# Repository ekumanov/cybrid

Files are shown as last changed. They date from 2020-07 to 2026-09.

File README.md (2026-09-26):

# Cybrid

**Cybrid** is an open-source MIDI controller.

## Introduction

**Cybrid** is a DIY project I finished in 2020. The main goal was to turn a grand piano action into a MIDI controller.
In digital piano terminiology instruments with a real wooden piano action are called _hybrid_ pianos. I own
one such instrument, the Yamaha AvantGrand N1X which is a digital piano with real grand piano action and realistic
piano hammers that are stopped by a cushioning rail instead of strings.
There are optical sensors that detect the hammer velocity and produce digital piano sound.
In other words, it's a hybrid between an acoustic piano and a digital piano. I really like the Yamaha AvantGrand concept
and wondered if I can re-create something similar as a DIY project. Since I participate on various Internet piano forums
with the CyberGene nickname, another user suggested that I name the project Cybrid (from **Cyber**Gene and **hybrid**).

I am a Java engineer and had no prior experience with programmable boards, low-level programming, electronics, DIY,
woodowrking, metal working, piano regulation, etc. which is why it took me quite some time to learn the basics of all these
things and combine them to produce the final project. It is also why some decisions I made are rather clumsy
and the final result is not very polished. I'm glad this project served as an inspiration to other similar projects though.
Some of them are better designed and are also more easily reproducible.

Here's a demo of the finished Cybrid controller (ctrl-click on the picture to open the YouTube video in a new tab):

Watch the video (https://youtu.be/x7ZbjIRRwVg)

This GitHub project contains just the PCB design, the software and the mechanical
considerations/descriptions of the controller. It may be used "as is" for anyone willing to recreate that project, or
can evolve into a more advanced and improved design that can be used as a basis, or inspiration for other (hybrid or regular) MIDI-controllers,
etc.

If you would like to discuss this project, there's a discussion thread on
the [PianoClack Forum](https://pianoclack.com/forum/d/107-cybrid-a-diy-midi-controller-with-grand-piano-action)

## Brief description

### Main Principle

The goal of the project is to detect the velocity of the piano hammers and trasnalate it into MIDI velocity. This is realized by
using
[Vishay CNY70](https://datasheet.octopart.com/CNY70-Vishay-datasheet-5434663.pdf)
optical sensors and
[Texas Instruments LM339](https://www.ti.com/lit/ds/symlink/lm2901.pdf)
voltage comparators (LM339AD package).

**The main principle of using voltage comparators to turn continuous analog signals into digital binary signals has been
suggested by Marcos Daniel, a member of the PianoWorld forums. Everything else, including the multiplexing, PCB design,
Teensy code and integration with a real grand piano action has been done by me.**

* The CNY70 is an optical proximity sensor that consists of a photoemitter (a LED) and a phototransistor. The
  phototransistor will change its collector current depending on the proximity of subjects to the sensor
* By measuring the voltage drop created by the collector current on a resistor and comparing it to a reference voltage,
  we will know whether the subject is within a predefined proximity.
* A voltage comparator is a device that has two voltage inputs and a digital output. One of the inputs is a reference
  voltage selected through a trimpot and the other input is the phototransistor output voltage. If the phototransistor
  output voltage is higher than the reference voltage, the output of the comprator will be digital 1, otherwise it will
  be digital 0.
* Thus we can turn the continuous analog sensor signal into a discrete digital binary value that changes when
  the subject crosses a predefined distance

That is important because the LM339 voltage comparator is very fast when comparing two voltages. It takes just a few
nanoseconds to switch its digital state. That allows for a very fast distance detection, or more specifically whether
the hammer is either closer than, or farther than the preset distance point. In other words, the comparator will provide a digital output
of 1 whenever the hammer crosses that distance and stays closer to the sensor, and will switch back to zero when the
hammer crosses that point on its way back and moves away from it. By using that principle, we can avoid slow
analog-to-digital conversion. (As you will see in the following paragraphs, if we scan through all 88 keys of a piano,
and rely on just ADC to read the exact position of each hammer, might be a tricky task for many reasons.
First, because most programmable controllers such as Arduino/Teensy, etc. have only a few (1 or 2) ADC chips and a single
conversion takes microseconds which would cumulatively lead to inability to scan the entire keyboard without introducing
huge latency and without missing the very fast hammer motion. And second, even if fast ADC-s are used, it will require that we
multiplex analog signals and that's not a trivial task since there will be noise, etc.)

So, we can configure two preset distance points through two trimpots and use two voltage comprators. We will have two digital
outputs from the two comparators and by measuring the time it takes for the hammer to pass between the two points (i.e.
the comprators' outputs switch from 0 to 1), we can calculate velocity.

### Additional details

#### Multiplexing

A standard way of reading multiple sensors through limited number of inputs is through multiplexing, i.e. using
specialized chips that can
(roughly speaking) switch between multiple inputs and then channel them through a single line. However a particular problem
with this approach is that there is a switch delay and in this particular implementation scanning speed is of highest
importance. To work around that, we can use a programmable controller with as many inputs as possible, and one such board is the
[Teensy USB Development Board](https://www.pjrc.com/teensy/). It has 58 digital input/output lines.

#### Grouping

We can gather multiple scanned notes into a group, then select a group, read all the sensor data (each sensor outputting
two digital signals corresonding to two distances, as seen above), then switch to the nextg group, etc. until we read
all notes. In the current implementation, for a 88-key piano, we have 3 binary signals per note (see below why 3 and not
just 2) and a group is made of 5 notes. This means we have 18 groups
(the last group only contains 3 notes and not 5):

**18 groups x 5 notes** = 90 notes (-2 unusued in the last group) = 88 notes

**3 signals per note** = 15 signals per group

**18 groups x 15 signals** = 270 binary signal lines

Now, if we can enable only one group at a time, we can then read the 15 signals from each group by reusing one and same
15 input signal lines. Thus we will have 18 *group enable* lines from the Teensy (outputs) and 15 input lines shared by
all the 18 groups.

**18 outputs + 15 inputs = 33 digital input/outputs.**

Seems like we can go without using a mux/demux chips. Instead we will share inputs between groups. However, the problem
is if we just wire the corresponding inputs of the groups, and since they will continuously generate differing signals (
one group can generate high signal at the same time another group will generate low signal), it means they will be
short-circuiting themselves. To avoid that, we will use digital transceiver chips. A transceiver is a simple device that
has a certain number of digital inputs and digital outputs. It will repeat on the outputs the same digital signal that
it has on the corresponding input. Each transceiver chip also has an enable/disable line. When in disabled state, the
outputs will be in high impedance state (regardless of input signals), 
and that is how we solve the problem of short-circuiting. For the current solution we use
[SN74LVC245A](https://www.ti.com/lit/ds/symlink/sn74lvc245a.pdf) Octal Bus Transceivers With 3-State Outputs (
SN74LVC245ADWR package).

#### Circuit boards, wiring, power

There are three types of printed circuit boards

* **Sensor PCB** - these are very small PCB-s each containing a single CNY70 sensor and placed above each hammer shank base.
  In a 88-key piano there will be 88 of these. 5 of these connect to a single Note PCB.
* **Note PCB** - these are the group modules. Each one serves 5 Sensor PCB-s. Each Sensor PCB is connected through three
  wires (5V, signal, GND). There are three trimpots per sensor PCB, for setting the predetermined detection distances.
  The uppermost trimpot is for sensor 1 which is the closest distance to the hammer stop rail. The Note PCB-s also
  contain a jumper that is set to one of 18 positions to determine the group number of the Note PCB. Note PCB-s also
  have an IDC34 socket. The Note PCB-s should be aligned on a horizontal line and be connected through a single IDC34
  cable that has 18 IDC connectors. Each Note PCB has two power sockets. Each power socket has three lines (5V, 3.3V,
  GND). The two power sockets are wired to each other so that one can be used as power input and the other as power
  output for chaining to the next Note PCB. There are two voltages because the CNY70 sensors and the comparators are
  powered by 5V, however the digital signals from the transceivers as well as their power supply is 3.3V. The Teensy 3.6
  controller supports only 3.3V voltage (unlike Teensy 3.5 and older but they are slower)
* **Teensy PCB** - this one contains the Teensy controller, an IDC34 socket for controlling the Note PCB-s, power
  inputs/outputs to chain to the Note PCB-s, and possibility to connect other devices (e.g. a sustain half-pedal to the
  analog inputs.) It has s USB-B input that's used only for power input. The Teensy controller itself has a micro-USB
  for connection to the computer to transmit MIDI. The Teensy controller itself is powered through that USB connection.
  Everything else requires an external power, for instance using the USB-B input socket. In the current implementation
  an iPad charger is used and it's sufficient to provide 2W of power which is the entire consumption. On the Teensy PCB
  there's also a jumper that can draw 3.3V power from the Teensy controller and send it to the Note PCB-s, however
  that's not recommended since there might be short circuits or problems with the Note PCB-s that can burn the Teensy.
  In the current implementation a pretty simple 3.3V voltage regulator is added through a small customized breadboard
  attached to the Teensy PCB, drawing from the 5V power.

The PCB-s are designed in the free KiCad editor.

**To Be Done** (a BOM or list with exact elements)

#### Scanning algorithm

The program is written in the Arduino compatible language of Teensyduino. It would sequentially enable each Note
module (a note module is serving 5 notes x 3 inputs). For each module all the 15 inputs are read. For each optical
sensor there are three predefined sensor distances (set through trimpots and with the calibration utility programs) that
are referred to in the code as sensor1, sensor2, sensor3. Sensor3 corresponds to the damper being removed from the
string, it is halfway from the hammer travel. Sensor 2 is where escapement happens. Sensor1 is where the hammer touches
the rail (in reality it should be a bit further to allow for the scanning logic to catch that moment because the hammer
will rebound quickly and sensor1 will be activated for only a brief moment).

***Active low* logic is used.**

Sensor distance signal lines stay active as long as the hammer is at this distance or closer to the rail. This means
when sensor1 is active (low), sensor2 and sensor3 are also active, etc.

When the hammer activates sensor2 for the first time, it means we
"start" measuring duration and we remember the timestamp of that event.

When the hammer activates sensor1 for the first time, it means we have a
"hit" and so we produce a MIDI note-on event based on the duration. A velocity is obtained through an in-memory map that
holds logarithmic velocity values that have been pre-calculated.

On its way back, if the key is held, the hammer will stay within sensor3 activation region and so the sound will
sustain. Once the key is released, the hammmer will deactivate sensor3 (high signal) and that's when MIDI note-off is
sent.

**These timestamp recordings and events are recorded sequentially
(group by group, input line by input line), because we want to give equal chance for each event to be recorded as soon
as it happens. For instance, once we read the event "hammer passed through C4 middle sensor" we will continue scanning
other keys and sensors and we will be able to check that hammer then passed through C4 sensor 1 (i.e. a hit)
only on the next full loop. Therefore it's of the highest importance that there's no delay in any scanning speed. The
fastest the entire loop finishes, the more precise the velocity calculation will be.**

#### Building the firmware

The sketches are in `src/teensy` (main firmware in `main/`, calibration utilities in `utils/`), each in its own
folder so they open directly in the Arduino IDE with [Teensyduino](https://www.pjrc.com/teensy/td_download.html)
(set *Tools > USB Type* to *MIDI* for the main firmware).

They can also be built with [PlatformIO](https://platformio.org/) using `platformio.ini` in the repository root:

* `pio run` builds all sketches (V1.3, V1.2 and the three calibration utilities) for Teensy 4.1
* `pio run -e v1_3 -t upload` builds and flashes the main firmware (`v1_3_teensy36` targets a Teensy 3.6)

`test/host/run.sh` runs the firmware against a simulation of the V1 hardware on the computer. It checks that the
firmware never makes two outputs fight on the cable or bus, and that it behaves like a grand piano action (one note per
stroke, faster hammer = louder, repetition with the key held, aborted presses, rail rebounds). It also compares the
MIDI output with a reviewed reference (`test/host/expected/v1_3.txt`), so any change in behaviour shows up as a diff;
accept an intended change with `UPDATE_EXPECTED=1 test/host/run.sh`. GitHub Actions runs these tests and builds all
sketches on every push; the `.hex` files can be downloaded from each run's artifacts and flashed with the Teensy Loader.

TBD (velocity map calculation) for quick calculation a velocity map is pre-calculated on program startup and held in
memory to allow for a quick "
duration -> MIDI velocity" value to be read from memory rather than being calculated all the time (since it also
includes logarithms, etc. which is slow.)

TBD (group velocity offset calculation) the high keys hammers are lighter than the low ones. If we don't account for
that, the produced MIDI velocity value is too high and the key sounds too loud. Therefore an offset needs to be applied
and pre-calculated, so the velocity map is actually further split into groups (
corresponding to the note PCB groups.)

TBD (half-pedal mapping) uses the ADC module.

#### Calibration

_(Copy-paste from a forum discussion)_

If you mean the Calibrate_Sensor_1/2/3 programs in the utils folder, those are actually temporary programs meant to assist in calibrating the sensors. Let me do some explanations first:

Not sure why I used the confusing word "sensor" but I actually meant sensor "point". Each optical sensor is used to detect three predefined distances of each hammer:

- Point 3: Hammer at half the distance between rest point and stop rail. When the hammer is above that point, I consider this as the damper being lifted, so once I detect a hit and send a Note ON event, then I will wait for the hammer to drop below this point and is when I will send Note OFF.
- Point 2: Hammer at 1mm from the stop rail (this is where hammer is released from the jack, i.e. the escapement), we start measuring duration from this point
- Point 1: Hammer at (or very close to) the stop-rail, this is where we stop measuring duration and derive velocity from it

Now, through the trimpots you set where those three distances for each sensor (hence hammer) are. In order to quickly do that, I created the three helper programs for each sensor point.

Here's the procedure:
- Upload the corresponding program for the corresponding "sensor" point (1, 2, 3).
- The program is a very simple logic that detects if any sensor (for any hammer) is at a distance equal or closer to the corresponding point and if true, will lit the Teensy LED

To facilitate the initial rough calibration I use:

- A simple wooden block that has such dimensions that when I put it at the stop-rail and lift the hammer, so that the hammer touches the block, then hammer is at exactly half the blow-distance (point 3).

- I use a thin plastic strip with 1mm thickness for point 2.

- For point 1 I just lift the hammer until it touches the stop-rail.

- So, depending on which of these three utility programs are loaded, I use the corresponding wooden block, or strip, or the stop rail itself, and I lift each hammer one by one until it touches the wooden block, the strip or the stop-rail. And I observe the LED and turn the corresponding trimpot until the LED is lit.

Once I am ready, I then upload the main program loop and surprisingly the above calibration is already pretty close to the final result and the piano is pretty playable at this point. It takes less than 10 minutes to do the above and I doubt you have to do it often once performed for the very first time.

I then perform a finer manual adjustment without any tools, only playing the keys one by one and I devised the following procedure:
- I play staccato notes with a high velocity and adjust the first position so that the corresponding key stops being detected. That means that I set the point way too high and the hammer cannot reach it because it's stopped by the rail before it. Then I begin to slowly back off until the hammer "appears" again. If you stop at that point, you will notice that very low velocity might still be missed because the stop-rail cushioning is not compressed enough to trigger it. Or, very high velocity strikes get missed because they are so quick, and the point is set so high, that the scanning doesn't have enough time to detect the hammer while at the point 1. That's why we need to give it some leeway and back off enough the trimpot, so that the hammer is always detected in the peak point, regardless of velocity. Once there, we have the top point set at a good enough distance
- We then proceed to fine-setting the second point. Because adjusting the first point effectively changes the distance between it and the second point, it effectively changes the loudness of that hammer. So, I proceed fine-tuning the second point by ear, choosing a realistic velocity response of the key. This might sound like a very demanding task but surprisingly for me, it is a satisfying thing to do, since I felt like a real piano master who fine-tunes his piano. And actually it's very easy to feel where the good position is.
- I will optionally fine-tune the third point to be where I need the note OFF to happen. My experience is it's not very important.

People often comment on how the above procedure is the main reason they didn't like that solution and how tedious it is, but in fact it's a pretty quick procedure that takes no more than 20-30 minutes in total and is required only the very first time. From there on, only an occasional touch-up is needed. 

### Mechanical Piano Considerations

TBD

### Known Problems

TBD

* stable power with low-ripple is very important. Currently the power comes from a USB-B socket and is chained through
  wires from the Teensy PCB to all the Note PCB-s. This is not a good solution and needs improvement.

### TBD (more details coming...)

### Misc Info

**Because I've been communicating with some people and got some questions, I will paste here raw excerpts from emails if
it can help.**

All SMD elements are of 0603 size/footprint which according to my research at the time was the smallest possible size
that's still possible to be hand soldered. It's pretty tiny as it turned out, so I used one of those specialty glasses (
for jewelry, etc.) that you put on your head with changeable magnification glasses.

There are three resistor values that have been used:

240 Ohm one on each sensor boards: https://store.comet.bg/en/Catalogue/Product/9812/

4.7 kOhm (5 on each module board R18, R28, R38, R48, R58, these are the resistors that are on top of the module board
above the trimpots): https://store.comet.bg/en/Catalogue/Product/9910/

10 kOhm - all other resistors: https://store.comet.bg/en/Catalogue/Product/35586/

On the Teensy board I haven't soldered any resistors. My idea was to limit current draw for powering sustain pedals, so
there's place for resistors but that needs to be calculated ad hoc. I was in a hurry, so haven't limited the Kawai pedal
but there seems to be no problems.

All capacitors are 100 nF (there are 6 capacitors on each module board **on the back side**, they are the only elements
to be soldered on the back side besides the sockets that connect the sensor
boards): https://store.comet.bg/en/Catalogue/Product/50624/

The trimpots are 10k, however due to insufficient quantity I also purchased 20k, I think it makes no difference:
https://store.comet.bg/Catalogue/Product/5925/
https://store.comet.bg/en/Catalogue/Product/6318/

The comparators are LM339AD and are through the Farnell
catalog: https://store.comet.bg/en/CatalogueFarnell/Product/1895017/

The transceivers are SN74LVC245ADWR, however they seem to not be available anymore. I see a similar
part (https://store.comet.bg/CatalogueFarnell/Product/506771/) which is however TSSOP-20 and I'm not sure if its
footprint is the same as SOIC-20 as the original part. Needs to be checked. (P.S. Seems like half the size, so not
compatible)

P.P.S. The transceivers are available at
Mouser: https://eu.mouser.com/productdetail/texas-instruments/sn74lvc245adwr?qs=WzgTT80quPGdOFCXqni3uA==

Here are some of the other parts I ordered:
https://store.comet.bg/en/Catalogue/Product/5003090/
https://store.comet.bg/en/CatalogueFarnell/Product/291323/
https://store.comet.bg/en/Catalogue/Product/286934/
https://store.comet.bg/en/Catalogue/Product/10079/#e30%3D
https://store.comet.bg/en/Catalogue/Product/10151/
https://store.comet.bg/en/Catalogue/Product/10151/
https://store.comet.bg/en/Catalogue/Product/2944/#e30%3D
https://store.comet.bg/en/Catalogue/Product/3116/#e30%3D
https://store.comet.bg/en/Catalogue/Product/17820/#e30%3D (soldered on the backside of the module board, facing the
sensor boards, so that short 10cm three-wire female-female dupont cables I ordered through some Chinese eBay seller can
be used to connect each sensor board to the module boards, I don't have the link for the cables anymore)
https://store.comet.bg/en/Catalogue/Product/20826/ (I cut those into smaller 3-pin pieces which was PITA, these are the
corresponding connectors on the sensor boards to the above part. Before attaching these two parts you need to really
check what the mechanical placement will be of your sensor boards and module boards on your piano and from there to
decide whether you need angled or straight sockets, etc. their orientation, whether you mount them on the backside of
the sensor board or probably an angled one on the front or back, etc. it's flexible and depends on your construction and
ability to connect in either straight line or probably a n arced cable... I thought a lot on that and ultimately decided
on my current variant visible also in the pictures)
https://store.comet.bg/en/Catalogue/Product/48762/ - used to daisy-chain power from a module board to module board, two
of these per module board

Regarding the CNY70 sensor, it's soldered so that the writings/label on the sensor-cube (there is some text only on one
of its sides) is next to the label "
CNY70" on the sensor board. The chips are soldered so that the notch (small marking/hole) matches a corresponding small
circle printed on the PCB.

To daisy-chain the power between module boards I used single-core hard cables that I bought from a hobby-shop, those
cables are used for breadboards.

On the Teensy board there's the possiblity to connect a jumper that will get the 3.3V from the Teensy but I wouldn't
recommend it and I don't use it. Intead I used an improvised 3.3V regulator that is getting 5V from the main USB-power
line (the iPad charger), look at the pictures, a bit awkward but works. I don't remember the regulator part, I bought by
asking on the store but there's some writing on it and I can shoot it. But I guess every regulator will work since the
3.3V consumption isn't high.

On each module board you need to use a jumper to denote the module board index by which it will be read by the software.
On the left side of the IDC connector top to bottom are 1-9, and on the right side top to bottom are 10-18, you start
with 1 at the lowest part of the keyboard.

Making the IDC cable is major PITA. I created my own clamping contraption, you can see it on the pictures. Make this
your last step because the sensor boards are not equally spaced because due to the action brackets the hammers are
grouped and so some module boards will not be centered behind adjacent 5 sensors but would be behind 5 sensors with a
bracket in between. So once you mount the module boards, then you design the IDC cable. And mine was made intentionally
wavy because I already wasted one trying to make it straight but that's a difficult task.

Also, seems like a I screwed up the Teensy IDC orientation and so to make the IDC cable finally connect at the Teensy
without twisting it, the Teensy board needs to be upside-down

For the sustain pedal, I power it from the Teensy PCB and it's connected to A21 on that board, however they swapped it
between Teensy 3.6 and 4.1, so on the 4.1 that's not A21 but luckily it's still an analog input with another name, can't
remember, maybe A20 (see in the code I have a comment for whether you use 3.6 or 4.1).

### Pictures

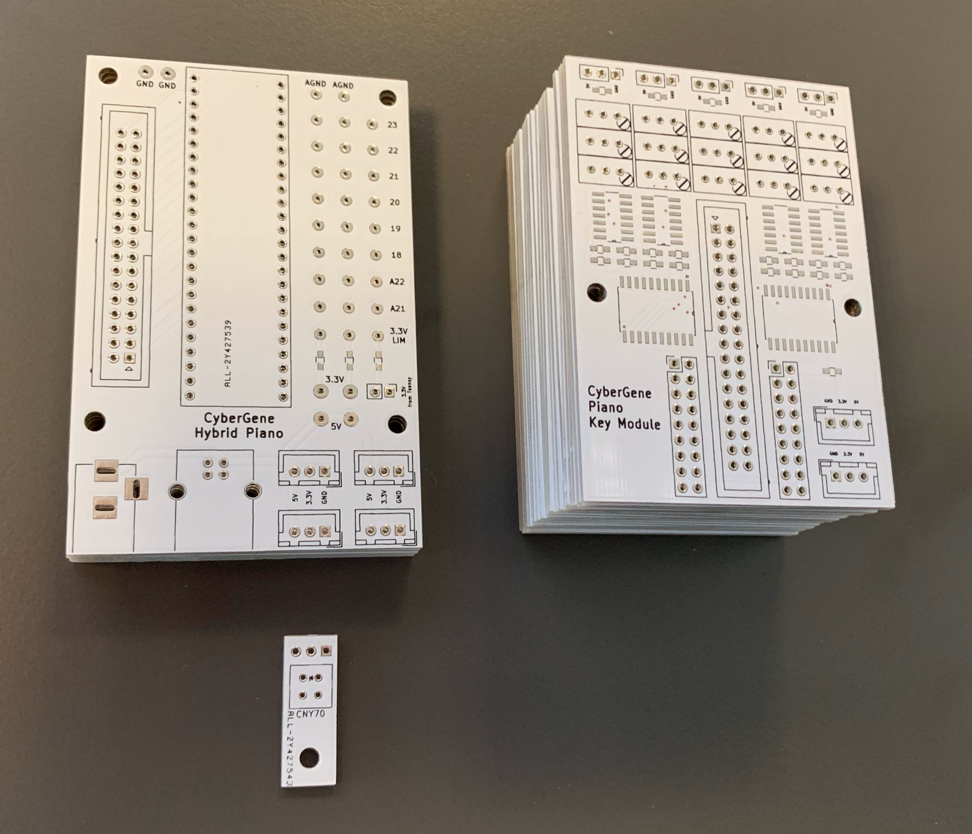
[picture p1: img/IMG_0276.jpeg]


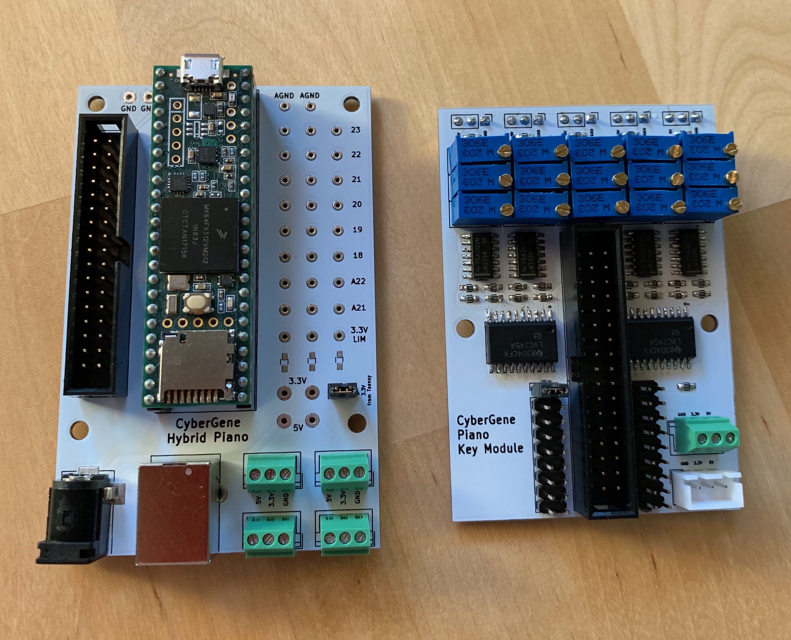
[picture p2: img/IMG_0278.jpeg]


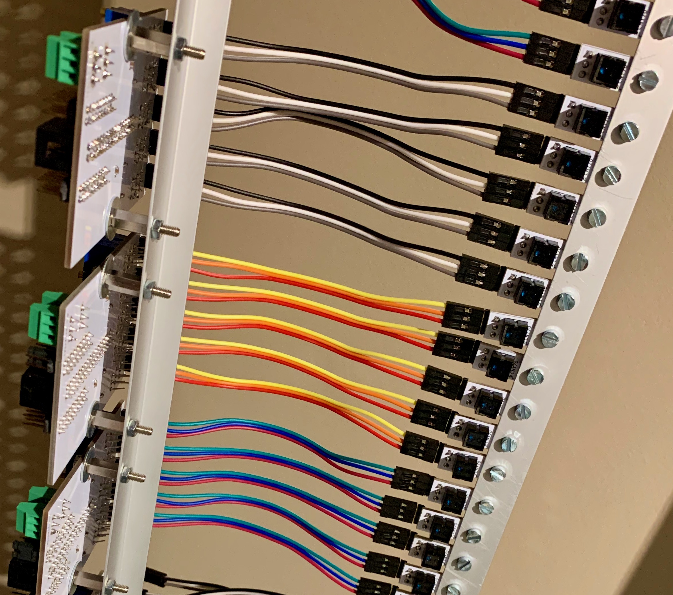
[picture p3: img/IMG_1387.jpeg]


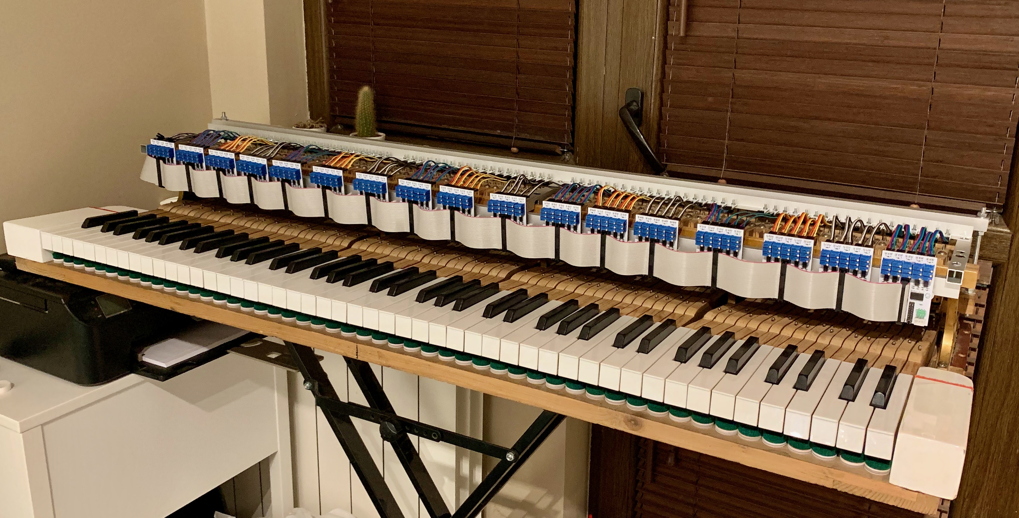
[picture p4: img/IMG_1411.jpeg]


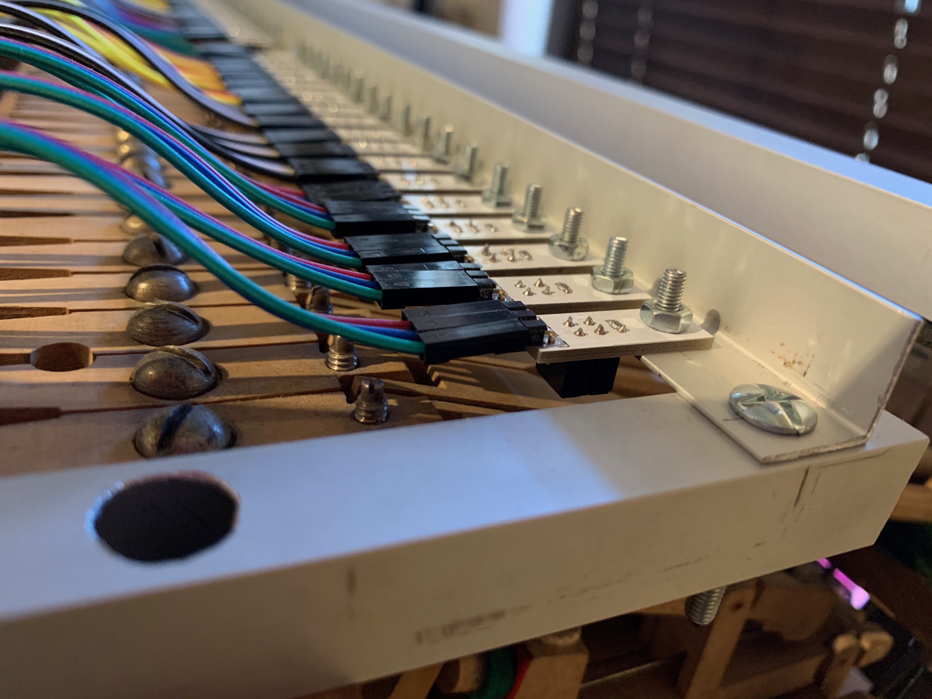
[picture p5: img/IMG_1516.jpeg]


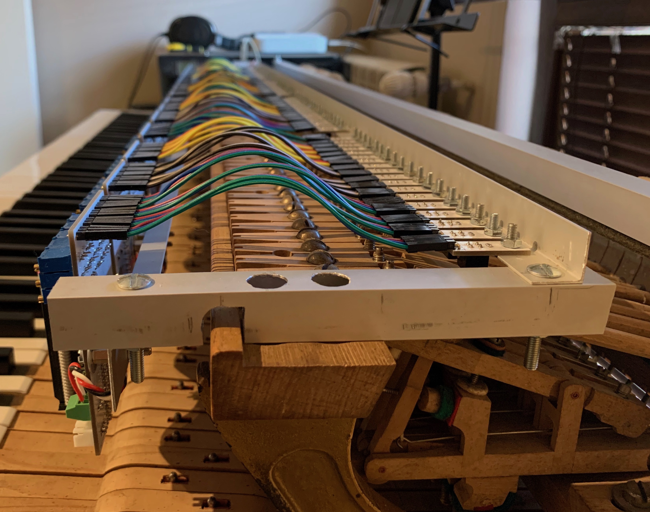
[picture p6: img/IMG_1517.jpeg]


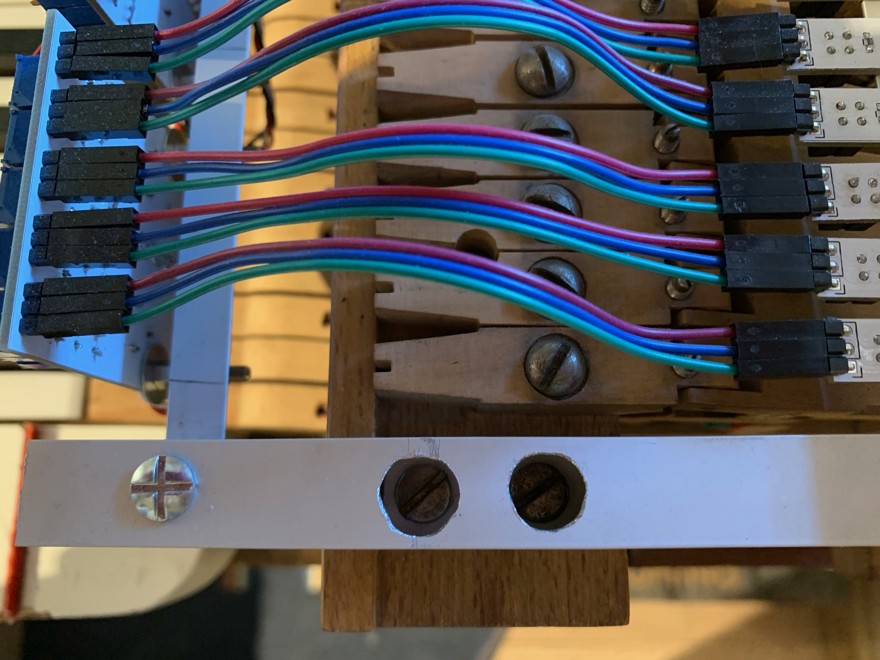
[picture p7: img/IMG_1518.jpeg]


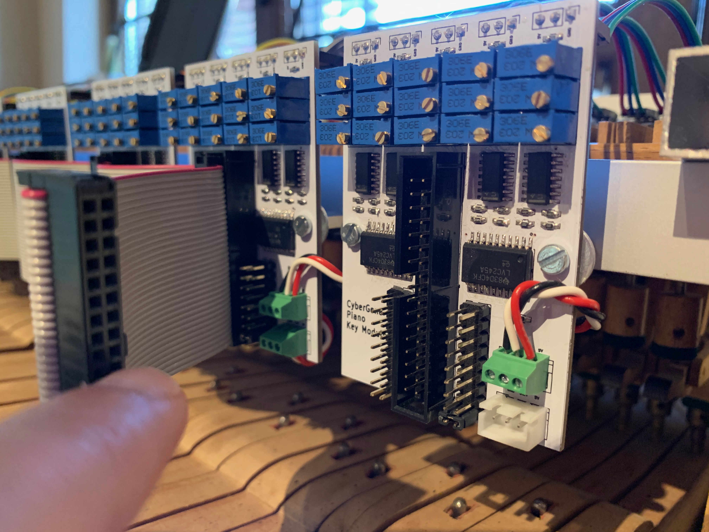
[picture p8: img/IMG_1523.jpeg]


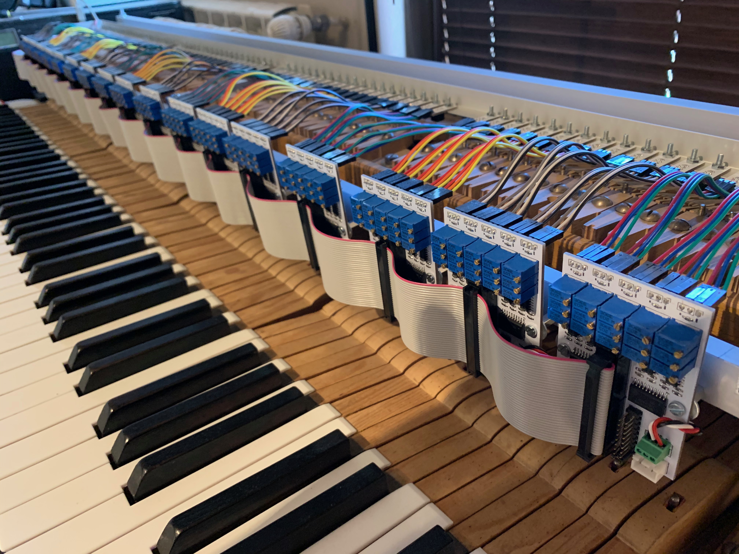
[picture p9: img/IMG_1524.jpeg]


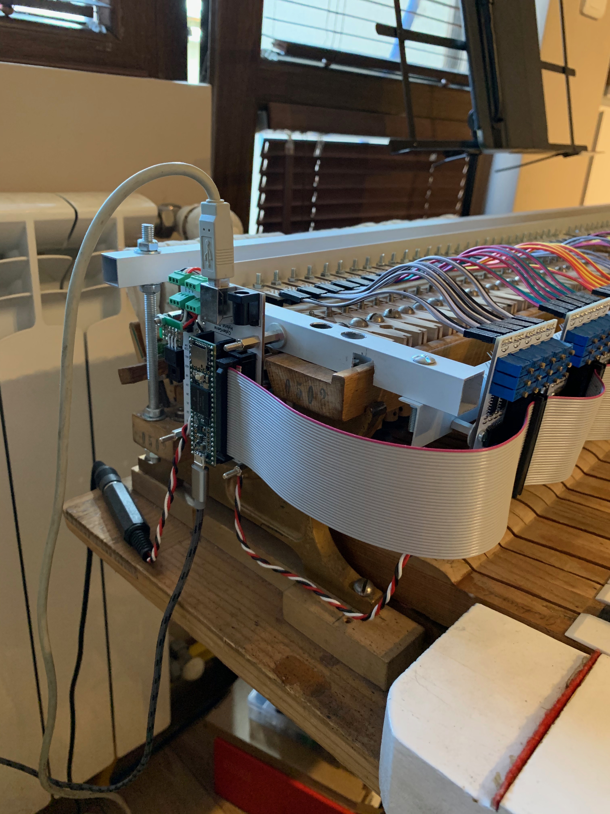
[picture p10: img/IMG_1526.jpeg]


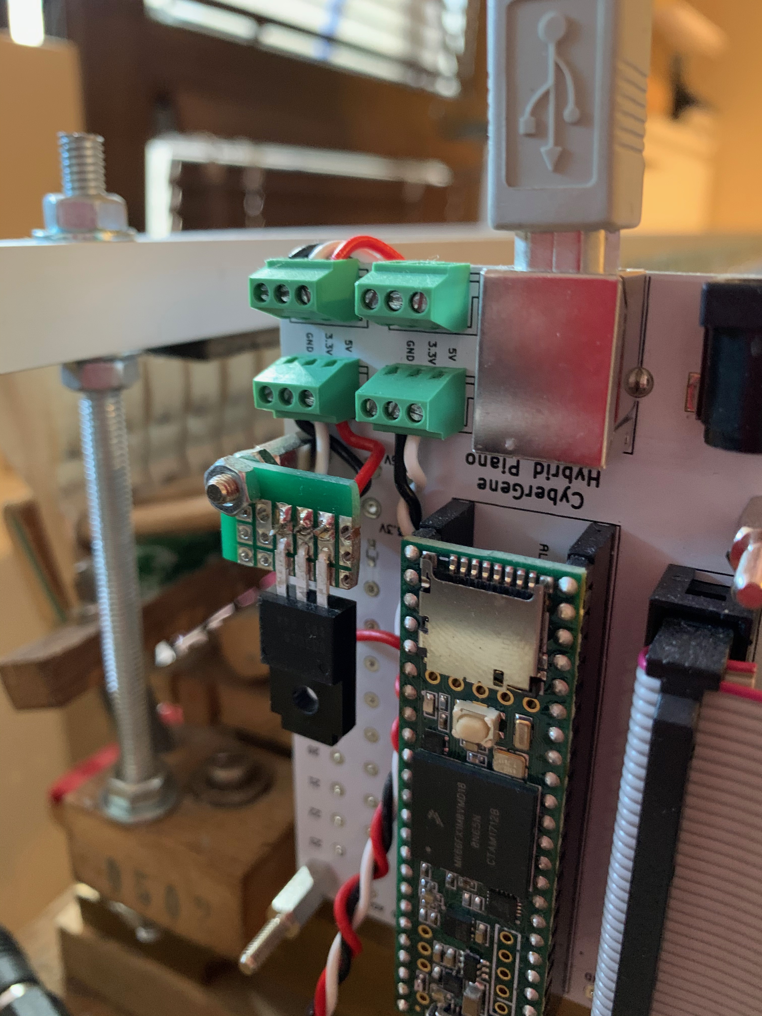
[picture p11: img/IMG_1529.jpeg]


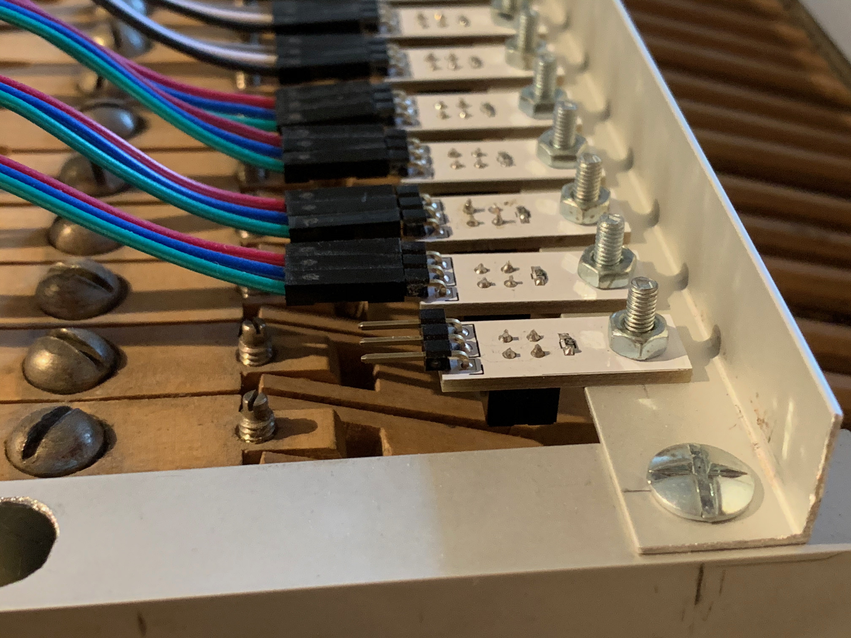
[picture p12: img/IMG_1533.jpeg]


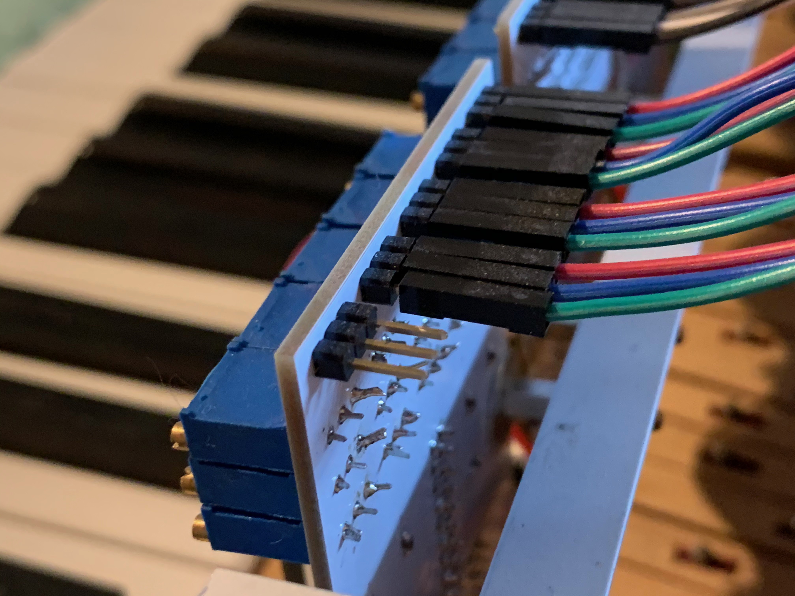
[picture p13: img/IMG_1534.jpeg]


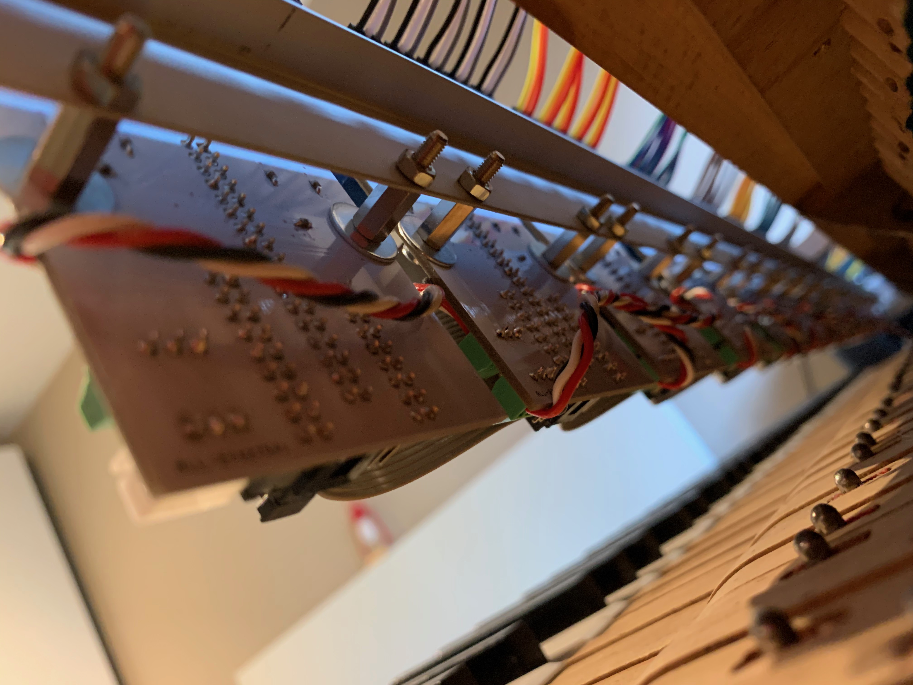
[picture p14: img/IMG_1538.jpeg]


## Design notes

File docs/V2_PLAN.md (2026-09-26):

# Cybrid V2 — Project Review & Redesign Plan

*A review of Cybrid V1 (hardware as built, firmware V1.2 / V1.3) and a rough approach for a future major
redesign. Revised after a netlist-level review of the PCBs, and again after a scan-timing analysis of the
compiled firmware and the V1.3 rework; see [Revision notes](#9-revision-notes).*

**TL;DR:** The sensing concept — optical hammer-shank detection with time-of-flight velocity — is excellent
and should stay. The three things a V2 should eliminate are the 255–264 hand-tuned trimpots, the fixed
three-point binary sensing, and the hand-made 18-drop IDC cable. All three disappear with one
architectural shift: sample the sensors *continuously* with cheap modern MCUs and do the thresholding
in **software** instead of hardware comparators. The hard problem in V2 is not sampling speed but
**signal-to-noise and power**: the sensor sees only a fraction of a millimetre of motion around the
strike point, and the V1 sensor LEDs alone draw ~7 W. Phase 1 exists to measure exactly that. Around
this, the repo needs a round of professionalization (license, BOM, structure, CI) that is worth doing
even before any redesign.

---

## 1. What V1 is

A grand piano action turned into a MIDI controller. One CNY70 reflective optical sensor per hammer,
mounted on a rail above the hammer shank near its flange; each sensor feeds three LM339 comparators
whose reference voltages (set by trimpots) define three distance gates: damper point, escapement
point, strike point. A Teensy scans 18 groups of 5 notes through tri-state bus transceivers over a
shared ribbon cable, measures the hammer's flight time between the escapement and strike gates, and
maps it to MIDI velocity through a precomputed logarithmic table with per-group grading. A continuous
half-pedal is read via ADC.

**Scan speed.** The recorded figure is a full-keyboard scan of ~8.9 µs (~112 kHz, ~0.5 µs per group),
measured with V1.2. Because that measurement is uncertain, the scan time was also derived from the
compiled firmware: one idle `loop()` was run in an ARM emulator (Unicorn) to count every instruction and
GPIO access exactly, and those counts were priced with published GPIO access times (Teensy 3.6: ~8
cycles per pin read; Teensy 4.1: fast GPIO on the 600 MHz AHB bus, a few cycles). Estimates for one
85-key scan, fast / **typical** / slow:

| Firmware | Teensy 4.1 (600 MHz) | Teensy 3.6 (256 MHz) | Settling per group |
|---|---|---|---|
| V1.2 | 3.1 / **5.1** / 8.1 µs | 15.3 / **19.3** / 24.2 µs | ~40–110 ns (4 dummy reads) |
| V1.3 as first committed | 8.4 / **11.8** / 16.0 µs | 22.2 / **27.1** / 33.6 µs | 100 ns |
| V1.3 now (pipelined, port snapshots) | 2.8 / **3.6** / 5.0 µs | 9.6 / **11.6** / 14.5 µs | ≥100 ns + 20 ns dead time |

The 8.9 µs figure fits only a Teensy 4.1; a Teensy 3.6 cannot scan that fast. At fortissimo (~300 µs
flight time, ~0.14 velocity steps per µs) a 5 µs scan means at most ±0.7 steps of timing jitter —
below what the ear resolves. That is competitive with commercial scanners, and a direct measurement
with a cycle-counter benchmark build is still to be done on the instrument.

## 2. What's good — keep these ideas

- **The core trick is clever and proven.** Hardware comparators turn a slow analog problem into a
  fast digital one; a 9 µs binary scan of 88 keys beats what naive ADC multiplexing could do in 2020.
  Latency and velocity resolution are excellent, and the instrument demonstrably works (video, daily
  playing, derivatives inspired by it).
- **It senses the right thing.** Hammer shank motion at the end of free flight is what an acoustic
  piano "measures", not key position. This is the reason the result feels right, and it must not be
  lost in a redesign.
- **Zero heavy math in the hot path.** Velocity lookup is O(1); event logic is a small, correct state
  machine (strike / escapement / damper / rest, with latches preventing double-triggering).
- **The detection logic matches a grand action.** Checked against piano mechanics rather than taken
  on trust: velocity linear in log(flight time) is linear in log(hammer speed), i.e. in dB — the right
  shape; a hammer caught by the backcheck rests below the escapement point, so repetition re-arms
  without a full release; a rebound off the rail counts as one note; an aborted press (escapement
  reached, no strike) is re-timed from the next approach. These are now executable checks (see §3,
  Firmware).
- **Sound low-level details.** Active-low logic with open-collector comparators pulled up to 3.3 V,
  transceiver outputs enabled one group at a time, a settling wait after each group switch, and a
  deadbanded pedal CC output.
- **Graded velocity.** The per-group velocity curves emulating graded hammer weight are a real musical
  feature — and in V1.2 they were hand-voiced on the instrument (the bass groups deliberately share
  flatter curves). That voicing is data worth preserving into V2.
- **Modular hardware.** Tiny sensor satellites decoupled from logic boards accommodate the uneven
  hammer spacing at action brackets; all boards are 2-layer and hand-solderable.
- **Honest documentation.** Known flaws, empirical constants, part links, and a written calibration
  procedure that encodes real regulation experience. That procedure is domain knowledge V2 should
  turn into software.

## 3. What's holding it back

### Hardware
- **255–264 trimpots.** Three per key, each set by hand with a wooden block, a plastic strip, and an
  LED. Analog thresholds drift with temperature, LED aging, supply voltage, and mechanical settling.
  This is the #1 objection from people who considered reproducing the project — and the single
  biggest win available to a V2.
- **Binary three-point sensing.** Velocity comes from one time interval between two fixed points.
  No trajectory data, no note-off velocity, no bounce rejection beyond a latch, and the "voicing"
  of the instrument is physically frozen into trimpot positions.
- **Comparator operating limits.** The LM339s run from 5 V, so their input common-mode range ends at
  about 3.5 V (VCC − 1.5 V, less when hot). The trimpots span 0–5 V and the sensor emitter output
  (4.7 kΩ load) can approach 5 V with the hammer close. If both the reference and the sensor are above
  ~3.5 V the output is not guaranteed — most likely at the strike point. There is also no hysteresis:
  a slowly moving hammer can make an output chatter, and each chatter at the escapement gate restarts
  the flight timer (slightly too-loud soft notes).
- **The IDC-34 cable.** One hand-crimped ribbon with 18 connectors and a single ground wire for
  fast-switching signals over ~1.5 m. It is a single point of failure and was, in practice: a line
  shorted to group 7 permanently disabled group 16, and the workaround (`FAULTY_LINE 16`) ships as the
  *default* configuration of the reference firmware. It is also what limits the scan: after a group is
  enabled the cable needs time to settle (reflections from 17 connector stubs) — empirically about
  40–110 ns, since V1.2 on a Teensy 4.1 needed four dummy reads before reading a group. V1.2 also
  enabled the next group immediately after disabling the previous one, with no dead time, so two
  transceivers could briefly drive the bus together (V1.3 now adds 20 ns), and on the first scan after
  power-up it enabled all groups at once (harmless with the hammers at rest; V1.3 idles the lines HIGH
  first).
- **Power.** By the schematic values each CNY70 LED draws ~16 mA ((5 V − ~1.15 V) / 240 Ω), so 85 sensors
  take ~1.4 A — **about 7 W total**, not the ~2 W the README states (worth measuring). This runs through
  JST-XH connectors and solid-core wire daisy-chained over 17–18 boards, with only 100 nF ceramics on
  the boards and no bulk capacitance anywhere; the USB-B and barrel-jack 5 V inputs are tied together
  without a diode, and 3.3 V comes from an improvised regulator on a breadboard. The README lists
  ripple as a known problem; this is why.
- **Power sequencing.** The Teensy is powered from the computer's USB, everything else from a charger.
  With the charger on and the Teensy unpowered, the transceiver outputs and the 10 kΩ enable pull-ups
  back-feed the Teensy through its I/O protection diodes, and the group enables float, so several
  groups can drive the shared bus at once.
- **Assorted friction.** Manual group addressing via jumpers; the ribbon connector is placed rotated
  (90° on the Teensy board vs 270° on the note boards), which forces the Teensy board to be mounted
  upside down; sensor connectors are numbered J1, J2, J5, J3, J4 left to right (so the RV5x trimpots
  serve the *third* key of a group) and this is documented nowhere; SN74LVC245ADWR sourcing; 0603
  hand-soldering as an entry barrier.

### Firmware
- **Two coexisting firmwares, the newer one unplayed.** `My_Hybrid_Piano_V1.2.ino` (the author's first
  firmware, played daily, heavily unrolled copy-paste) and `My_Hybrid_Piano_V1.3.ino` (an AI-assisted
  rewrite, never run on the instrument). V1.3 as first committed silently changed behaviour in three
  ways — it drove the shorted faulty line against group 7, dropped V1.2's hand-voiced bass curves (bass
  up to 11 velocity steps louder), and added a clamp that made the top treble jump by up to 11 steps —
  and it was over twice as slow as V1.2, because GCC did not inline the per-key function, so every
  input read went through a runtime pin lookup table. All of this is fixed, and V1.3 was then reworked:
  each group's 15 inputs are captured with 4 GPIO port-register reads and processed while the next group
  settles; the settling (≥100 ns) and dead-time (20 ns) waits are compile-time cycle counts; a build-time
  check stops the build if an input pin is not on a snapshotted port; pedal updates every 5 ms instead of
  20 ms. Its MIDI output is identical to V1.2 in simulation and it is estimated faster (see §1), but it
  still needs a session on the instrument before it can replace V1.2.
  Lessons for V2: behaviour-preserving changes need a test that compares outputs, and performance
  claims have to be checked against the compiled code, not the source.
- **Personal workarounds as defaults.** `PIANO_SIZE 85`, `FAULTY_LINE 16`, the author's specific
  pedal limits — a stranger flashing the reference firmware gets CyberGene's broken cable map.
- **Calibration requires re-flashing.** Three separate sketches, uploaded in sequence, plus manual
  trimpot work. Nothing is configurable at runtime and nothing is stored on the device.
- **An oversized lookup table.** 17 × 12187 bytes (~207 KB, most of a Teensy 3.6's 256 KB RAM). The
  curve reaches velocity 1 at ~5.6 ms, so more than half of every table is the constant 1. The table
  avoids a double-precision `log()` at note-on, which on a Teensy 3.6 is done in software (several µs,
  stalling the scan); on a Teensy 4.1 (double-precision FPU) or with `log10f` it is well under 1 µs.
  A ~5.6k-entry table, a small table with interpolation, or direct single-precision computation all
  work.
- **Magic constants with no recorded derivation.** `VEL_DISTANCE_FACTOR 1500.0` and `VEL_ADDITION 57.96`
  are redundant: the formula collapses to `v = m · (375.6 − 100 · log10(t_µs))`, i.e. one intercept and
  one slope. Nobody can adapt them to a different action geometry except by trial and error.
- **Engineering scaffolding — now partly in place.** There is a PlatformIO project (each sketch in its
  own folder, one environment per sketch), a GitHub Actions workflow that builds everything and uploads
  the `.hex` files, and host tests (`test/host`) that run the firmware against a simulation of the V1
  hardware as traced from the netlists (group lines, the shorted cable line, the shared bus, the pin and
  port mapping). The tests check the hardware (no two outputs or boards fighting), the piano behaviour
  above (one note per stroke, faster hammer never softer, repetition with the key held, aborted
  presses, rail rebounds, creeping presses), and a reviewed reference of V1.3's MIDI output, updated
  deliberately. Still missing: a changelog, releases, and a measurement of the real scan time.

### Repository & professionalism
- **No LICENSE file.** The README says "open-source", but legally the project isn't — nobody can
  safely reuse or fork it. This is a five-minute fix and the most important single item here.
- **53 MB of photos in git**, IDE config (`.idea/`) committed, KiCad autosave/backup files and
  generated gerbers committed alongside sources, file names with spaces and parentheses. (Moving the
  photos only stops the growth; shrinking the clone needs a history rewrite, which is optional.)
- **The README does five jobs at once** — concept, build guide, calibration manual, parts list,
  and raw email dumps — with `TBD` markers unchanged since 2020 and no BOM.
- **KiCad 5.0 (2018 format)** sources; current KiCad is several major versions ahead.
- **Build tooling quirk.** With the Arduino IDE / arduino-cli on Apple Silicon, the sketch prototype
  generator (`ctags`) is an Intel binary and needs Rosetta; the PlatformIO build does not.

## 4. The V2 decision: continuous sensing, software thresholds

V1's architecture is a smart workaround for one 2020 constraint: ADCs were too slow to scan 88 keys.
Nearly every V2-worthy pain — trimpots, fixed gates, drift, the giant calibration effort — is a
consequence of doing thresholding in *hardware*. Modern microcontrollers remove the constraint:
a $1–2 MCU samples a dozen or more analog channels at tens of kHz each. So:

> **Keep the CNY70-on-hammer-shank concept. Replace the comparator matrix with continuous per-key
> sampling and do detection, calibration, and voicing in software.**

**Timing check.** A fortissimo hammer head (~5 m/s) crosses the last ~2 mm in ~400 µs. The sensor sits
near the shank flange, so it sees the same *time* window but only a fraction of the *distance* (the
lever ratio, roughly 1/4–1/5, is to be measured). Sampling each key at ≥20 kHz gives 8+ samples in that
window; at 50–100 kHz with hardware oversampling (easy on the MCUs below) there are 20–40. Fitting a
line or curve through those samples should match V1's two-edge timing (9 µs quantization) — **if** the
signal-to-noise ratio is good enough.

**The real constraint is SNR, not speed.** Around the strike point the shank moves a few tenths of a
millimetre in front of the sensor. The CNY70 output rises steeply as the target approaches, but peaks at
a fraction of a millimetre and *falls* again closer in, so the mounting height must keep the strike
position on the monotonic side of the curve. The phototransistor's response time (tens of µs, slower
with larger load resistors) acts as a low-pass filter: a consistent lag is harmless for velocity, but it
has to be characterized. All of this is measurable in Phase 1 and decides the load resistor, ADC range,
and sample rate.

| V1 pain | V2 consequence of continuous sensing |
|---|---|
| 255–264 trimpots, manual calibration | Per-key auto-calibration: learn each key's rest/max reflection, store in flash; thresholds become percentages of the learned range |
| Drift (temperature, LED aging, supply) | Continuous re-baselining while the key is at rest |
| Fixed strike/escapement/damper gates | Arbitrary, per-key, runtime-adjustable thresholds; "voicing" from an app instead of a screwdriver |
| Velocity from 2 edges | Velocity from a fitted trajectory; bounce rejection; note-off (release) velocity; configurable curves per key |
| Comparator limits, no hysteresis | Gone — hysteresis and debouncing are software parameters |
| 18-drop IDC analog-ish bus | Short local analog runs + a simple digital bus |

## 5. Proposed V2 architecture (rough)

**Sensors — unchanged in spirit.** Keep the CNY70 (proven on this exact mechanical problem, cheap,
large sensing face) on tiny 3-wire satellite boards, outputting the raw phototransistor voltage. The LED
can stay on 5 V; only the emitter-load output must stay below the MCU's 3.3 V ADC reference, which is a
choice of load resistor. QRE1113/ITR8307 are fallbacks only if size, speed, or current demands it.

**Power budget — a first-class design item.** At V1's ~16 mA per LED, 88 sensors need ~1.4 A at 5 V.
A computer's USB port cannot supply that (500 mA for USB 2.0, 900 mA for USB 3.x; USB-C gives 1.5 A or
3 A only if the host advertises it). Options, to be chosen in Phase 1:
- lower LED current (e.g. 5 mA with a larger load resistor), if SNR allows;
- strobe each LED only around its own sample window (limited by the phototransistor's response time);
- a dedicated 5 V / 3 A supply (USB-C PD or DC jack) separate from the MIDI USB connection.

Either way: bulk capacitance per board, reverse-current protection between power inputs, and a design
where no board can back-feed an unpowered neighbour.

**Scanner boards — the new "note boards".** ~8 boards × 11 keys (instead of 18 × 5), each carrying a
small MCU that samples its 11 sensors, runs detection and velocity computation locally, and emits
compact events. The MCU needs **≥11 ADC inputs**, which rules out the RP2040 (4 ADC inputs) and RP2350
(4–8) unless external muxes are added. The **STM32G0 family** fits well (e.g. STM32G071: up to 16
external channels, 12-bit at 2.5 MS/s, hardware oversampling, and a ROM bootloader) and is cheap and supported by
assembly services. Analog paths shrink from "across the piano" to <10 cm.

**Interconnect.** Half-duplex RS-485 (or CAN-FD with an STM32G0B1/G4). Because each board computes its
own velocities, **no clock synchronization is needed**: the hub timestamps events on arrival, and a
polling interval of ~100 µs is far below audible latency. Position-based auto-addressing needs a
daisy-chained line (ADDR_IN → ADDR_OUT) in addition to the bus pair, so plan a **6-wire** locking cable
(A, B, ADDR, 5 V, GND, GND) instead of 4 — or keep jumper/DIP addressing. Run power on wires sized for
the LED current, not on the signal cable's thinnest conductors. An event is ~8 bytes {key, type,
velocity, timestamp}; even a glissando is trivial bandwidth.

**Latency budget (target).** Key-to-MIDI under ~2 ms end to end: detection (<0.5 ms after the strike
point), bus (<0.2 ms), hub processing, and USB-MIDI (1 ms frames at full speed).

**Hub board.** Teensy 4.1 (most mature USB-MIDI stack) or an STM32/RP2040 with TinyUSB. USB-C for
MIDI; power as above; one clean 5 V rail on the bus with a local 3.3 V LDO per board (this replaces the
breadboard regulator and the ripple problem); three pedal jacks with configurable curves; status LED;
optional DIN-5 MIDI out.

**Firmware.** One PlatformIO monorepo: `firmware/hub`, `firmware/scanner`, and a shared protocol +
velocity/calibration library written as portable C++ so the math runs under unit tests on the host.
GitHub Actions builds every commit; releases ship flashable artifacts. All configuration lives in
flash and is exposed over SysEx — flashing is never part of calibration again.

The V1 test approach carries over and gets stronger: the piano-behaviour checks become the
specification of the detection code, and in V2 the inputs are *recorded hammer trajectories* from the
Phase 1 rig instead of scripted zones, replayed through the scanner firmware on the host. Every
firmware image also includes a diagnostic that reports scan/sample timing measured with the CPU cycle
counter, so timing is measured on the device rather than estimated.

**Companion app.** Browser-based (WebMIDI SysEx — zero install; WebSerial only for firmware update,
since it is Chromium-only and Safari has no WebMIDI): live per-key position waveform, an auto-calibration
wizard that encodes the README's manual procedure, per-key velocity curve editor seeded with V1.2's
voicing, MIDI monitor, firmware update. This plays directly to the author's software-engineering
strengths and is the piece that will make V2 feel professional to other builders.

**MIDI features.** Note-on velocity (per-key + global curves), note-off velocity, CC64 half-pedal plus
two more pedals, channel configuration. Stretch: high-resolution velocity (CC#88) or MIDI 2.0 once
host support is worth it.

### Alternatives considered

- **Central ADC + analog muxes** (one Teensy, passive note boards): simpler, one firmware image, but it
  reintroduces long analog runs across 1.2 m of piano — exactly what V1's comparators were designed to
  avoid.
- **"V1.5": keep V1, replace trimpots with digitally set thresholds** (a multi-channel DAC or filtered
  PWM per note board). This removes manual trimpot work and enables software calibration with the
  proven timing path unchanged. But it keeps the binary three-point sensing, the IDC cable, the
  comparator limits and 72 comparator chips, and it needs a control bus to each board anyway. It is the
  lower-risk option if Phase 1 shows the CNY70 SNR is marginal for continuous sensing.

The distributed design is the honest fix. Cost is likely *lower* than V1, not just neutral: 264
multi-turn trimpots cost more than eight small MCUs, and ~72 comparators, ~36 transceivers and the
jumper headers disappear.

## 6. What deliberately stays

Hammer-shank optical sensing; CNY70 satellites; modular boards sized around action-bracket gaps;
85- and 88-key support; the calibration *procedure* (as software); the graded velocity concept and
V1.2's voicing (as per-key curves).

## 7. Roadmap

**Phase 0 — make V1 presentable (no redesign; roughly a weekend).**
*Done:* V1.3 regressions fixed and scan reworked; PlatformIO build; sketches in their own folders; host
simulation tests with piano-behaviour checks and a reviewed reference output; GitHub Actions building
all sketches and publishing `.hex` artifacts.
*Remaining:* Add a license (suggestion: CERN-OHL-P for hardware, MIT for firmware, CC-BY-4.0 for
docs/photos) — without this nothing is actually open source. Tag the tested state (V1.2) as `v1.0` and
create a GitHub release. On the instrument: play-test V1.3 against V1.2 and measure the real scan time
with a cycle-counter benchmark build (raise `MATRIX_SETTLING_DELAY_NS` if ghost notes appear); then
promote V1.3 or keep it marked experimental. Make its defaults generic (`FAULTY_LINE 0`, 88 keys) with
the author's settings in a separate config block. Restructure: `hardware/` (KiCad sources only; gerbers
become release artifacts), `firmware/`, `docs/` (README split into concept / build / calibration
pages), photos resized into `docs/images/`. Write the BOM that has been "TBD" since 2020. Document the
J1-J2-J5-J3-J4 connector order and the power findings above. Optionally, measure the real supply
current and the strike-point trimpot voltages.

**Phase 1 — feasibility rig (one octave).**
Prototype one scanner board (MCU + 11 CNY70 channels) mounted beside the existing V1 electronics on
the same action. Record raw trajectories and measure: displacement at the sensor around the strike
point, SNR vs LED current and load resistor, phototransistor response time, and the CNY70 peak
position relative to the strike point. Validate velocity extraction against V1's output on the same
strikes and against a repeatable reference (e.g. a weight dropped from fixed heights onto the key),
and prove auto-calibration. Pick the MCU, ADC arrangement, LED current and sampling rate from this data
rather than from guesses. Exit criteria: repeatability on the reference within ±1 MIDI step, no
systematic bias against V1 beyond what a curve fit removes, a key that calibrates itself, and a power
figure per key that fits the chosen supply.

**Phase 2 — full-system alpha.**
Eight scanner boards + hub (rev A), bus protocol with auto-addressing, calibration in flash, minimal web
app (live view, auto-cal wizard, curve editor). Replace V1 on the instrument and play it daily; iterate
on the data.

**Phase 3 — community release.**
KiCad 8/9 sources, fab + assembly-service outputs (gerbers, BOM, CPL for e.g. JLCPCB) so nobody has
to hand-solder 0603 parts, interactive BOM, mounting drawings (DXF/STEP) for the sensor rail,
assembly & calibration guide, `v2.0` release. Stretch: note-off velocity voicing, MIDI 2.0, optional
damper/key sensing add-ons.

## 8. Risks & open questions

- **SNR at the strike point** — the biggest technical risk (see §4). Mitigations: optimise mounting
  height and load resistor, oversampling, or fall back to the V1.5 alternative.
- **CNY70 spread and nonlinearity** — handled by per-key normalization and a per-key curve learned in
  calibration.
- **Power** — ~1.4 A of LED current at V1's settings; must be solved by design, not by the host's USB
  port.
- **Optical crosstalk / ambient IR** — V1's always-on LEDs worked inside the piano, so likely a
  non-issue; modulated LED drive is the fallback if not.
- **Firmware updates across 9 MCUs** — needs a bus bootloader or hub-proxied update (the STM32 ROM
  bootloader helps); decide in Phase 2, design the protocol for it in Phase 1.
- **Simulation vs. the real bus** — V1.3's timing and behaviour are verified only in simulation and by
  estimate; the real cable's settling time is known only indirectly (V1.2's four dummy reads). The
  play-test and on-device measurement in Phase 0 close this gap.
- **Scope discipline** — each phase ends in something usable (a clean V1 repo, a validated octave, a
  playable alpha, a shareable release), so the project can pause at any phase without being wasted.

## 9. Revision notes

**Second revision** — after deriving the scan time from the compiled firmware and reworking V1.3:

- **Scan speed:** added the emulator-based estimates for V1.2 and V1.3 on both boards; the recorded
  8.9 µs fits only a Teensy 4.1; timing jitter is shown to be inaudible either way.
- **Firmware:** V1.3 was 2× slower than V1.2 because GCC did not inline the per-key function; it is now
  pipelined with port snapshots, compile-time waits and a dead time, estimated at 3.6 µs typical
  (V1.2: 5.1 µs). Pedal updates every 5 ms instead of 20 ms.
- **V1.2 as reference:** V1.2 is the author's first firmware, not a specification. Its detection logic
  was checked against grand-action mechanics (added to §2); tests now check that behaviour and a
  reviewed reference output instead of "identical to V1.2". The bass voicing is kept because the
  trimpots were calibrated by ear together with it.
- **Cable:** empirical settling time (~40–110 ns), the missing dead time and the all-groups-enabled
  first scan added to §3.
- **Tooling:** PlatformIO, CI and host tests are in place (Phase 0 progress); V2 firmware inherits the
  test approach with recorded trajectories and an on-device timing diagnostic.

**First revision** — after tracing the KiCad netlists and PCB copper and comparing the two firmware
versions line by line:

- **Power:** corrected "~2 W" to ~7 W (from 240 Ω LED resistors); added the USB power limits, missing bulk
  capacitance, unprotected dual 5 V inputs, and back-feeding when the Teensy is unpowered.
- **New V1 hardware issues:** LM339 common-mode limit vs 0–5 V trimpots, no comparator hysteresis, a
  single ground in the ribbon, and the undocumented J1-J2-J5-J3-J4 order. The connector is *rotated*,
  not mirrored; pin numbers map 1:1.
- **Firmware:** the V1.3 regressions (faulty-line contention, lost bass voicing, treble clamp) are listed
  and are now fixed; "monotonicity enforcement" is dropped from the strengths (the curve is already
  monotonic, so it was dead code); the log()-cost claim is corrected for the Teensy 3.6; the velocity
  constants are shown to be redundant; the table is shown to be over half constant; the performance
  figures are attributed to V1.2.
- **V2 architecture:** the sensor sits near the shank flange, so the design limit is SNR and CNY70
  curve shape, not sample rate. The RP2040 is replaced (only 4 ADC inputs) by the STM32G0. Clock sync is
  removed (velocity is computed on the scanner board). Auto-addressing needs an extra daisy-chain line,
  so the bus is 6 wires. Added a latency budget, WebMIDI/WebSerial browser limits, a "V1.5" alternative,
  and a reference-based Phase 1 exit criterion in place of "±1 step of V1".

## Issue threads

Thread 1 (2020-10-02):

Kickstarter?

davidedelvento, 2020-10-02:
Hi Cybergene,
Have you considered making a kickstarter for this project? While still preserving its DIY status, it would be greatly simplified for people interested into it if we could "buy" a kit, with all the PCB produced, and most if not all of the soldering made, and most if not all the electronics parts included.

Myself, rather than having to find somebody who can make the PCBs for me, and then finding and ordering all the materials, and then soldering everything during my spare time, I'd rather pay somebody for doing that. Even finding somebody doing that locally where I live now, while possible, is lots of time and effort which I don't have (and would be removed from the mechanical setup of the action, trivets regulation, etc)

Just to be clear, I am not saying that you should do this work yourself! I can see from the pictures that you must have used an industrial-quality company for producing the PCBs. Could they make a larger batch and then ship them to different customers, worldwide? How about procuring the electronics parts and soldering, can they do that? When I was living in Rome the PCB company I worked with offered all these services, even with surface soldering (which is much more complicated)... so it should not be a big deal if you are already a customer and they offer it. Perhaps they have a minimum order to make it viable for them, and here is where kickstarter could help: if you do not reach such minimum size, nothing happens, otherwise the order is placed. As far as I am concerned, you can charge (in the price of the kit) for your time, effort and hassle, especially if they do not offer the shipping part...

perepou, 2020-11-05:
A great idea Davidedelvento. How good it would be! (By Google translate)

Closed 2025-05-06.

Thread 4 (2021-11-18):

velocity values consistency

jjYBdx4IL, 2021-11-18:
Hey there! Are you interested in checking out a method to check the consistency of velocity output values from your Cybrid and N1X and maybe some rubber contact based instrument? I have done some first tests, and the rubber contact based products seem to deliver pretty inconsistent results. I have written a simple VST plugin for Win64 to compute and display the velocity delta of two simultaneously pressed keys. I'm just not quite sure how the method of pressing two neighboring white keys at once itself is reliable. If your optical sensor devices show that it's pretty consistent, that would be very helpful. It would also show that optical sensors are a must have for serious players.

ekumanov, 2022-01-08:
Hey, sorry for the late reply, I just saw this. Sounds interesting, but the problems is I don't have the Cybrid anymore with me, had to store it in another apartment since I don't have space for it at home :( I only keep the N1X but I can test it for consistency too. Cheers!

ekumanov, 2022-01-08:
BTW, I created a piano forum where we can discuss things like that, feel free to join: https://pianoclack.com/forum/

davidedelvento, 2022-01-08:
I'll be happy to contribute to this one too, I'm building something similar to the Cybrid and active on said forum.

Closed 2022-01-08.

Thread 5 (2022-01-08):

Scanning speed and velocity mapping of Cybrid

davidedelvento, 2022-01-08:
Question: you mentioned a while back (I think it was on PW) that you needed an intense "mapping" to provide appropriate MIDI velocities from the measured times. Looking at your code a https://github.com/ekumanov/cybrid/blob/master/src/teensy/main/My_Hybrid_Piano_V1.2.ino#L220-L245 I think shows what you were talking about. I think I understand and can reverse engineer it, but I think a discussion is better. So the question is: how are you mapping from time to MIDI velocity, do you have a plot of the curve you are using with a range of parameter that you tried (and accepted or discarded) -- basically anything that is not already evident from the code section I linked and even anything that you'd like to add to explain about that code even if it's evident.

ekumanov, 2022-01-08:
@davidedelvento, see my answer here: https://pianoclack.com/forum/d/289-scanning-speed-and-velocity-mapping-of-cybrid/2

Closed 2022-01-08.

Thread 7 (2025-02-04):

100nF

TimBooo19890503, 2025-02-04:
Hi there,

can u tell me which smd Capacitor type is the correct?

The link doesnt work anymore.

ekumanov, 2025-02-04:
All SMD components are 0603 footprint m, and I think any capacitor will work.

TimBooo19890503, 2025-02-04:
Thanks for sharing your Projekt , i will start it right now :-)

ekumanov, 2025-02-04:
To be honest, there are better projects now, both design wise and easier to replicate. You can find a lot of information on the PianoClack forum.

TimBooo19890503, 2025-02-04:
There may well be better designs, but I really like your design, I like the many circuit boards, the option of 3 trimming potentiometers, I think this makes adjustments very precise, and I have already ordered all the material ;). I'm really excited about the project. I was able to get a Keller J Co Stuttgart keyboard from 1926 for 20 euros. In excellent condition, nothing is missing. This keyboard was built into a KAIM grand piano from 1927. I'll take a closer look at the forum. this will be a great project for 2025 :-D. Thank you very much and greetings from Bulgaria.

Closed 2025-05-06.

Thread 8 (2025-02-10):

Drill Layer

TimBooo19890503, 2025-02-10:
Hey CyberGene,

maybe did u have the Drill-Layer for the PCBs for me?

ekumanov, 2025-02-10:
Here's a file with all layers:

https://pianoclack.com/forum/d/107-cybrid-a-diy-midi-controller-with-grand-piano-action/145

I'll upload it to GitHub too when I have chance.

ekumanov, 2025-05-06:
Uploaded

Closed 2025-05-06.

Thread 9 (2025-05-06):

LED is still on.

TimBooo1989, 2025-05-06:
Hello, I have made great progress in the meantime, thank you very much for this great project.

I'm currently calibrating, sensor 1, up to group eleven my LEDs on the Teensy are off and I get the buttons calibrated, at group 11-14-17 it is permanently on and I can turn the potentiometer as I want nothing changes, so I thought of a faulty board. I connected board 4 to the sensors of board 11 and redirected it. No change, board 4 is on even though it was off before. it must have another reason., Is it because I only use 17 boards but the code is on 18? I have an 85-key piano. Do you have an idea? Alternatively, I have to test the IDE, I hope that there has not been an error. Best regards from Germany Tim.

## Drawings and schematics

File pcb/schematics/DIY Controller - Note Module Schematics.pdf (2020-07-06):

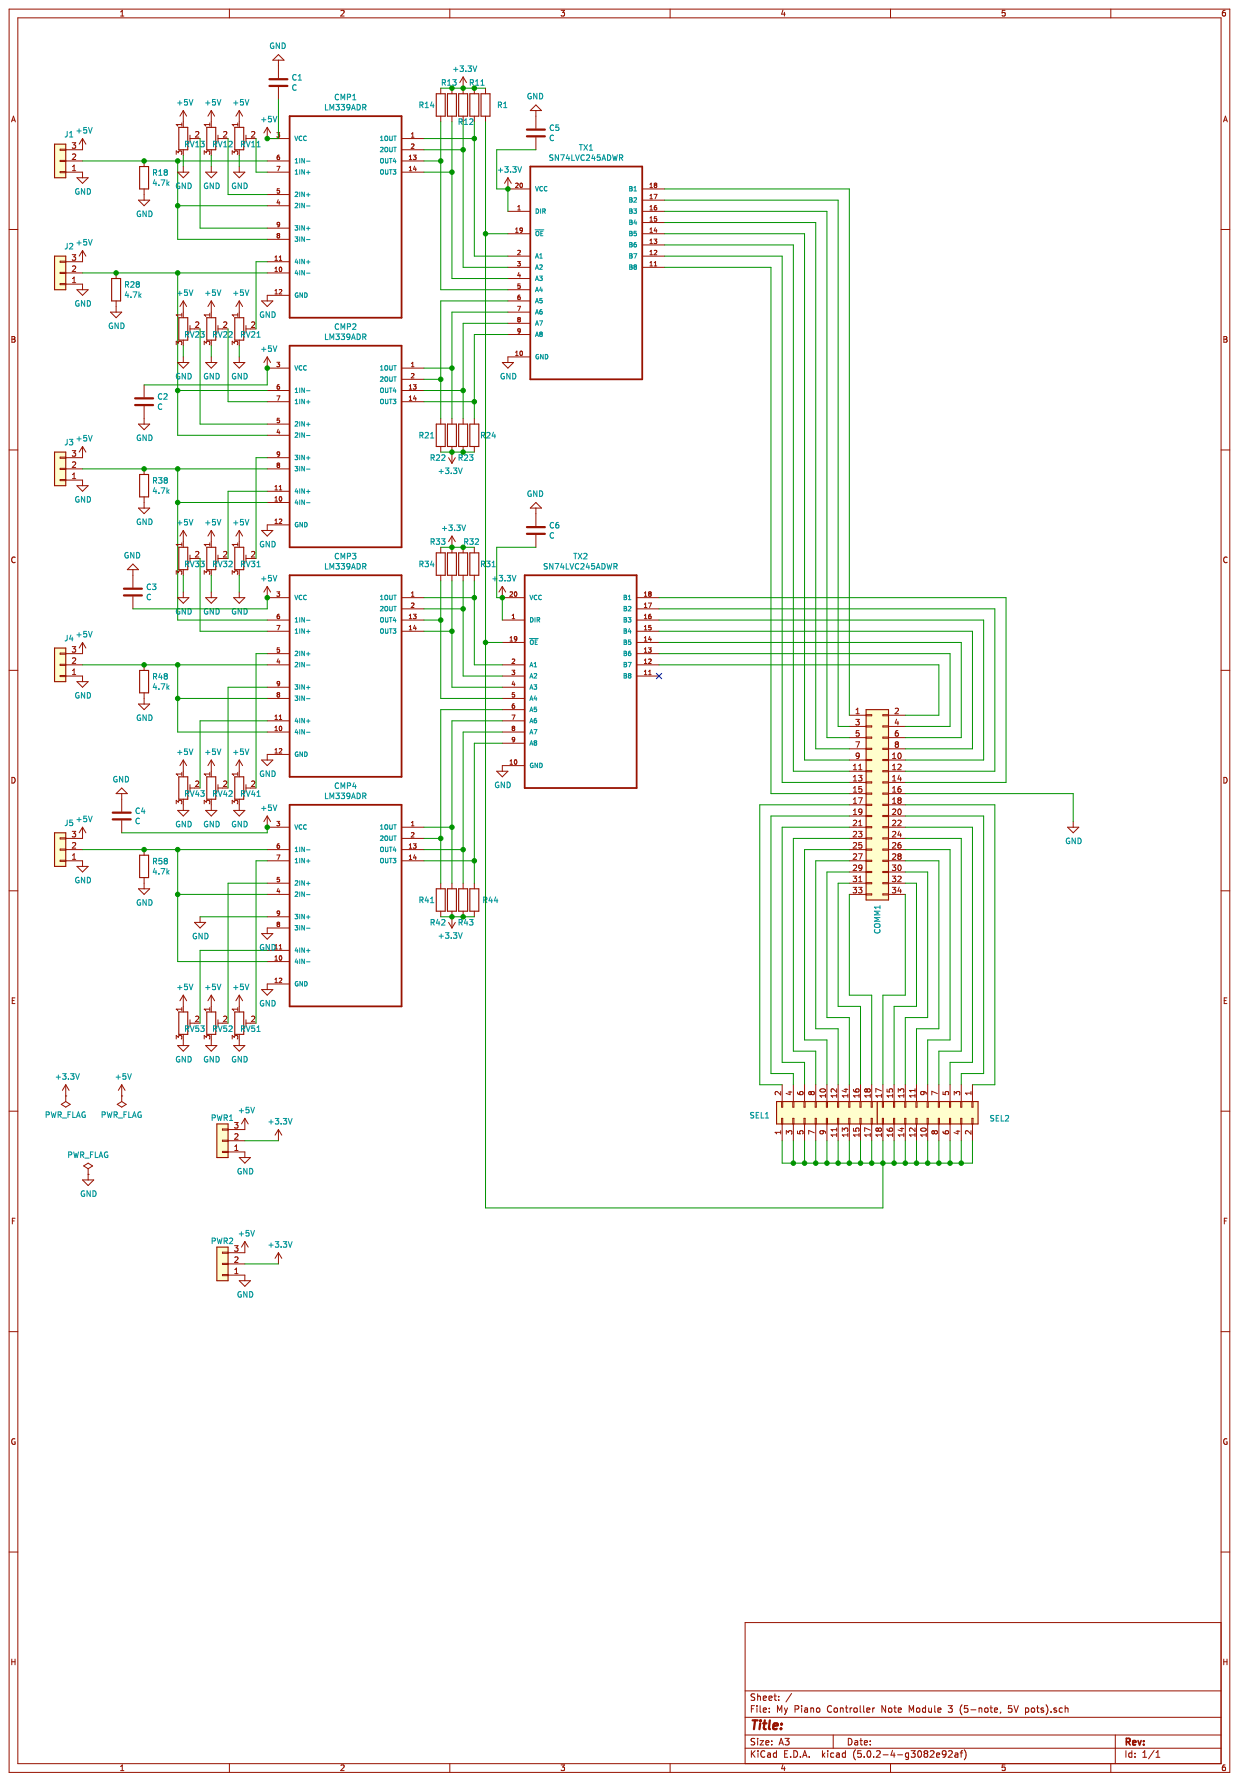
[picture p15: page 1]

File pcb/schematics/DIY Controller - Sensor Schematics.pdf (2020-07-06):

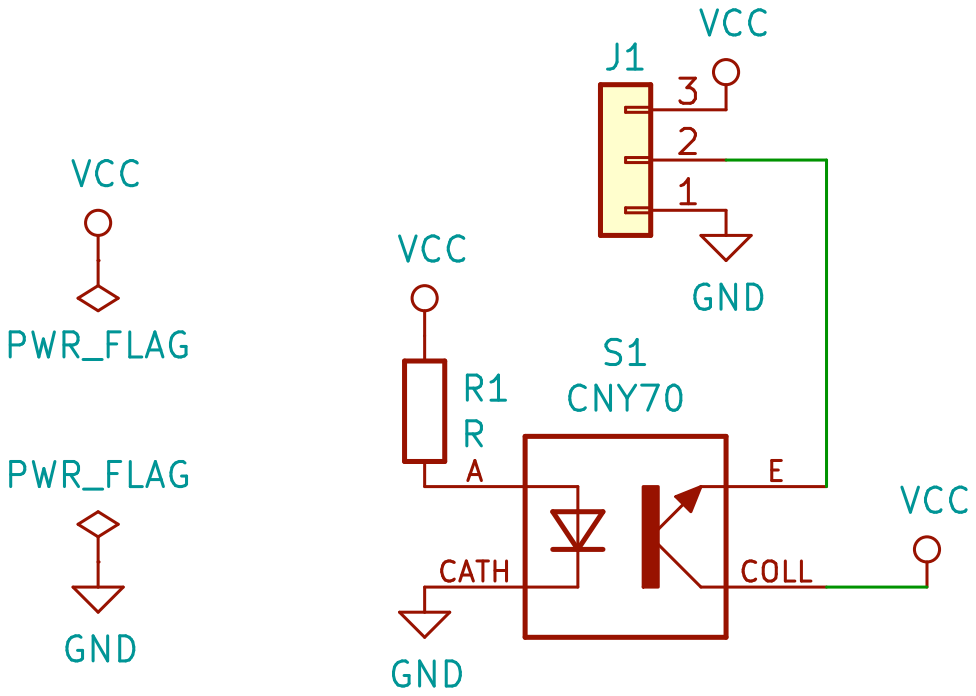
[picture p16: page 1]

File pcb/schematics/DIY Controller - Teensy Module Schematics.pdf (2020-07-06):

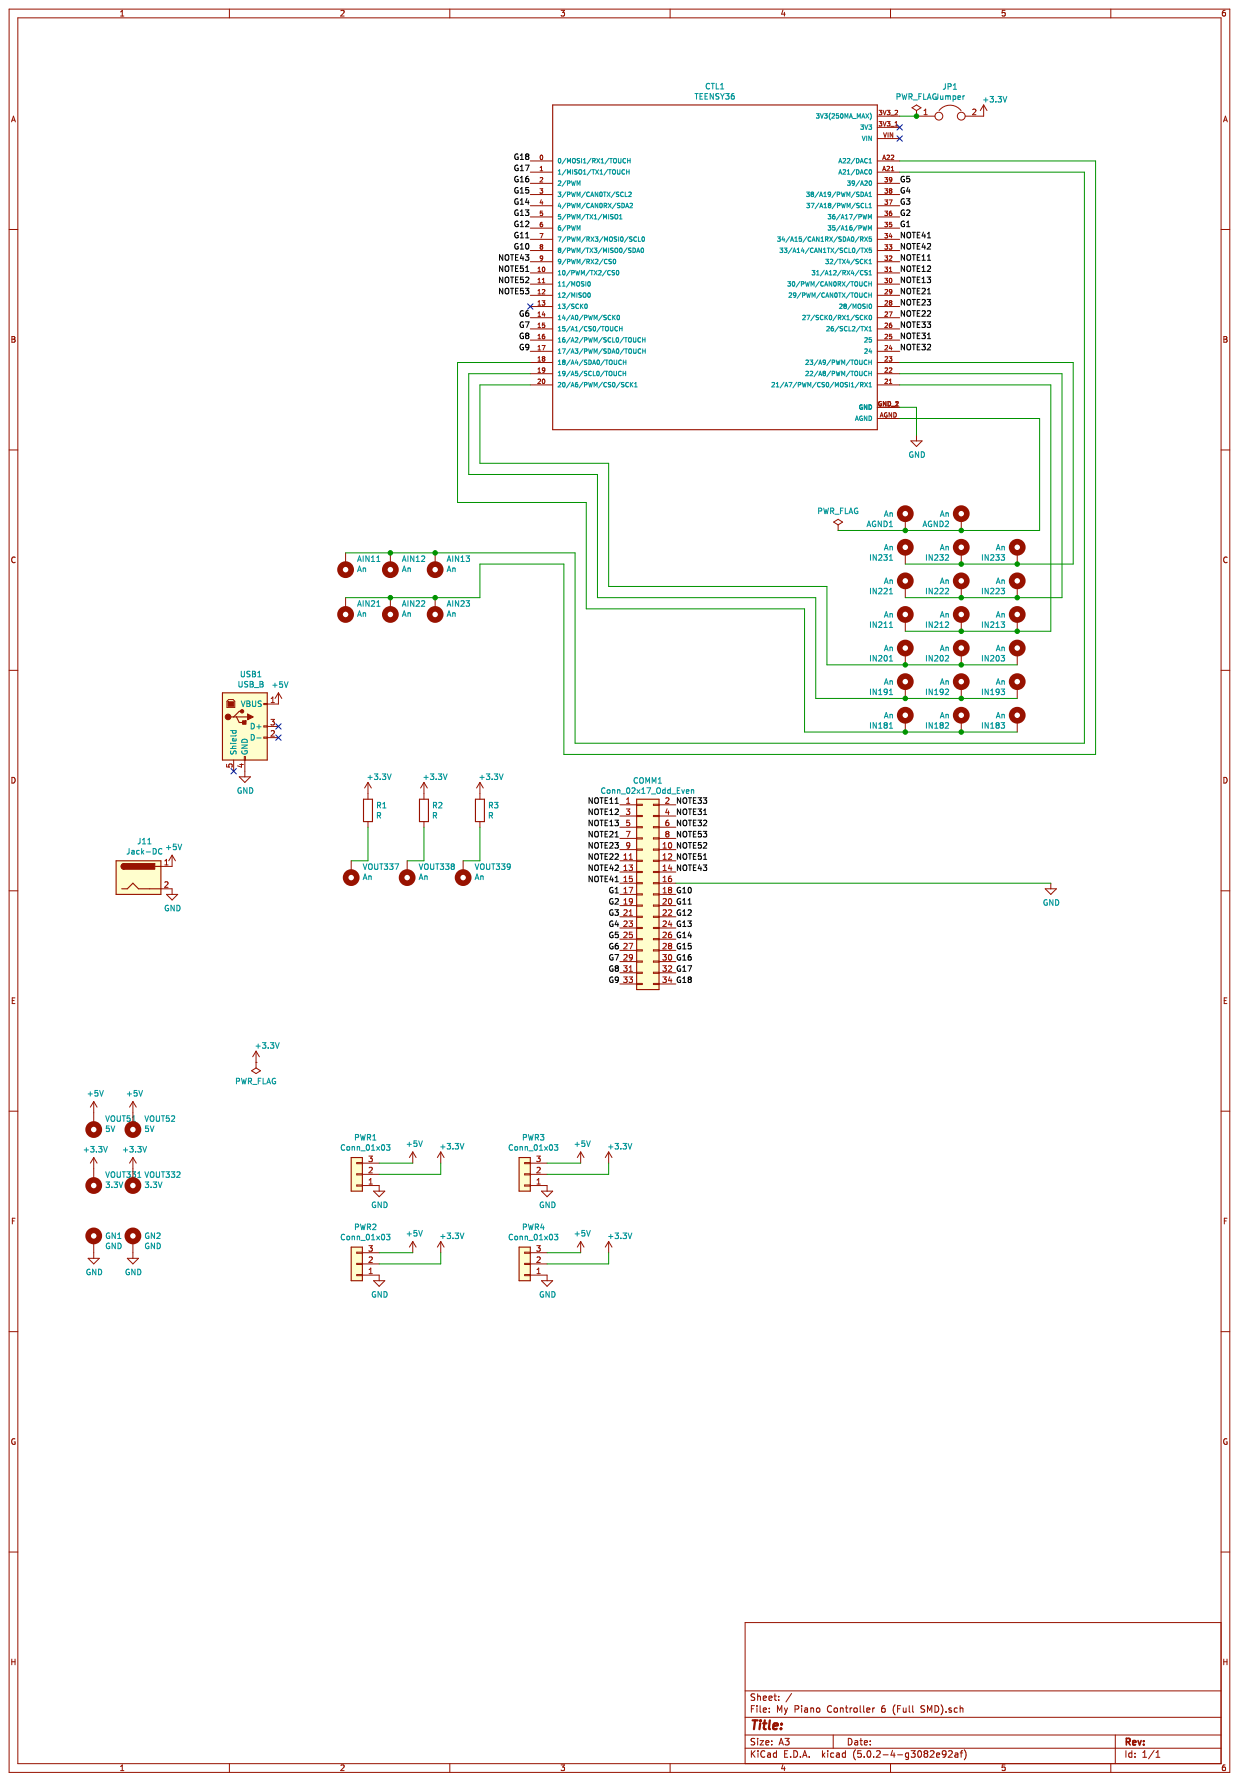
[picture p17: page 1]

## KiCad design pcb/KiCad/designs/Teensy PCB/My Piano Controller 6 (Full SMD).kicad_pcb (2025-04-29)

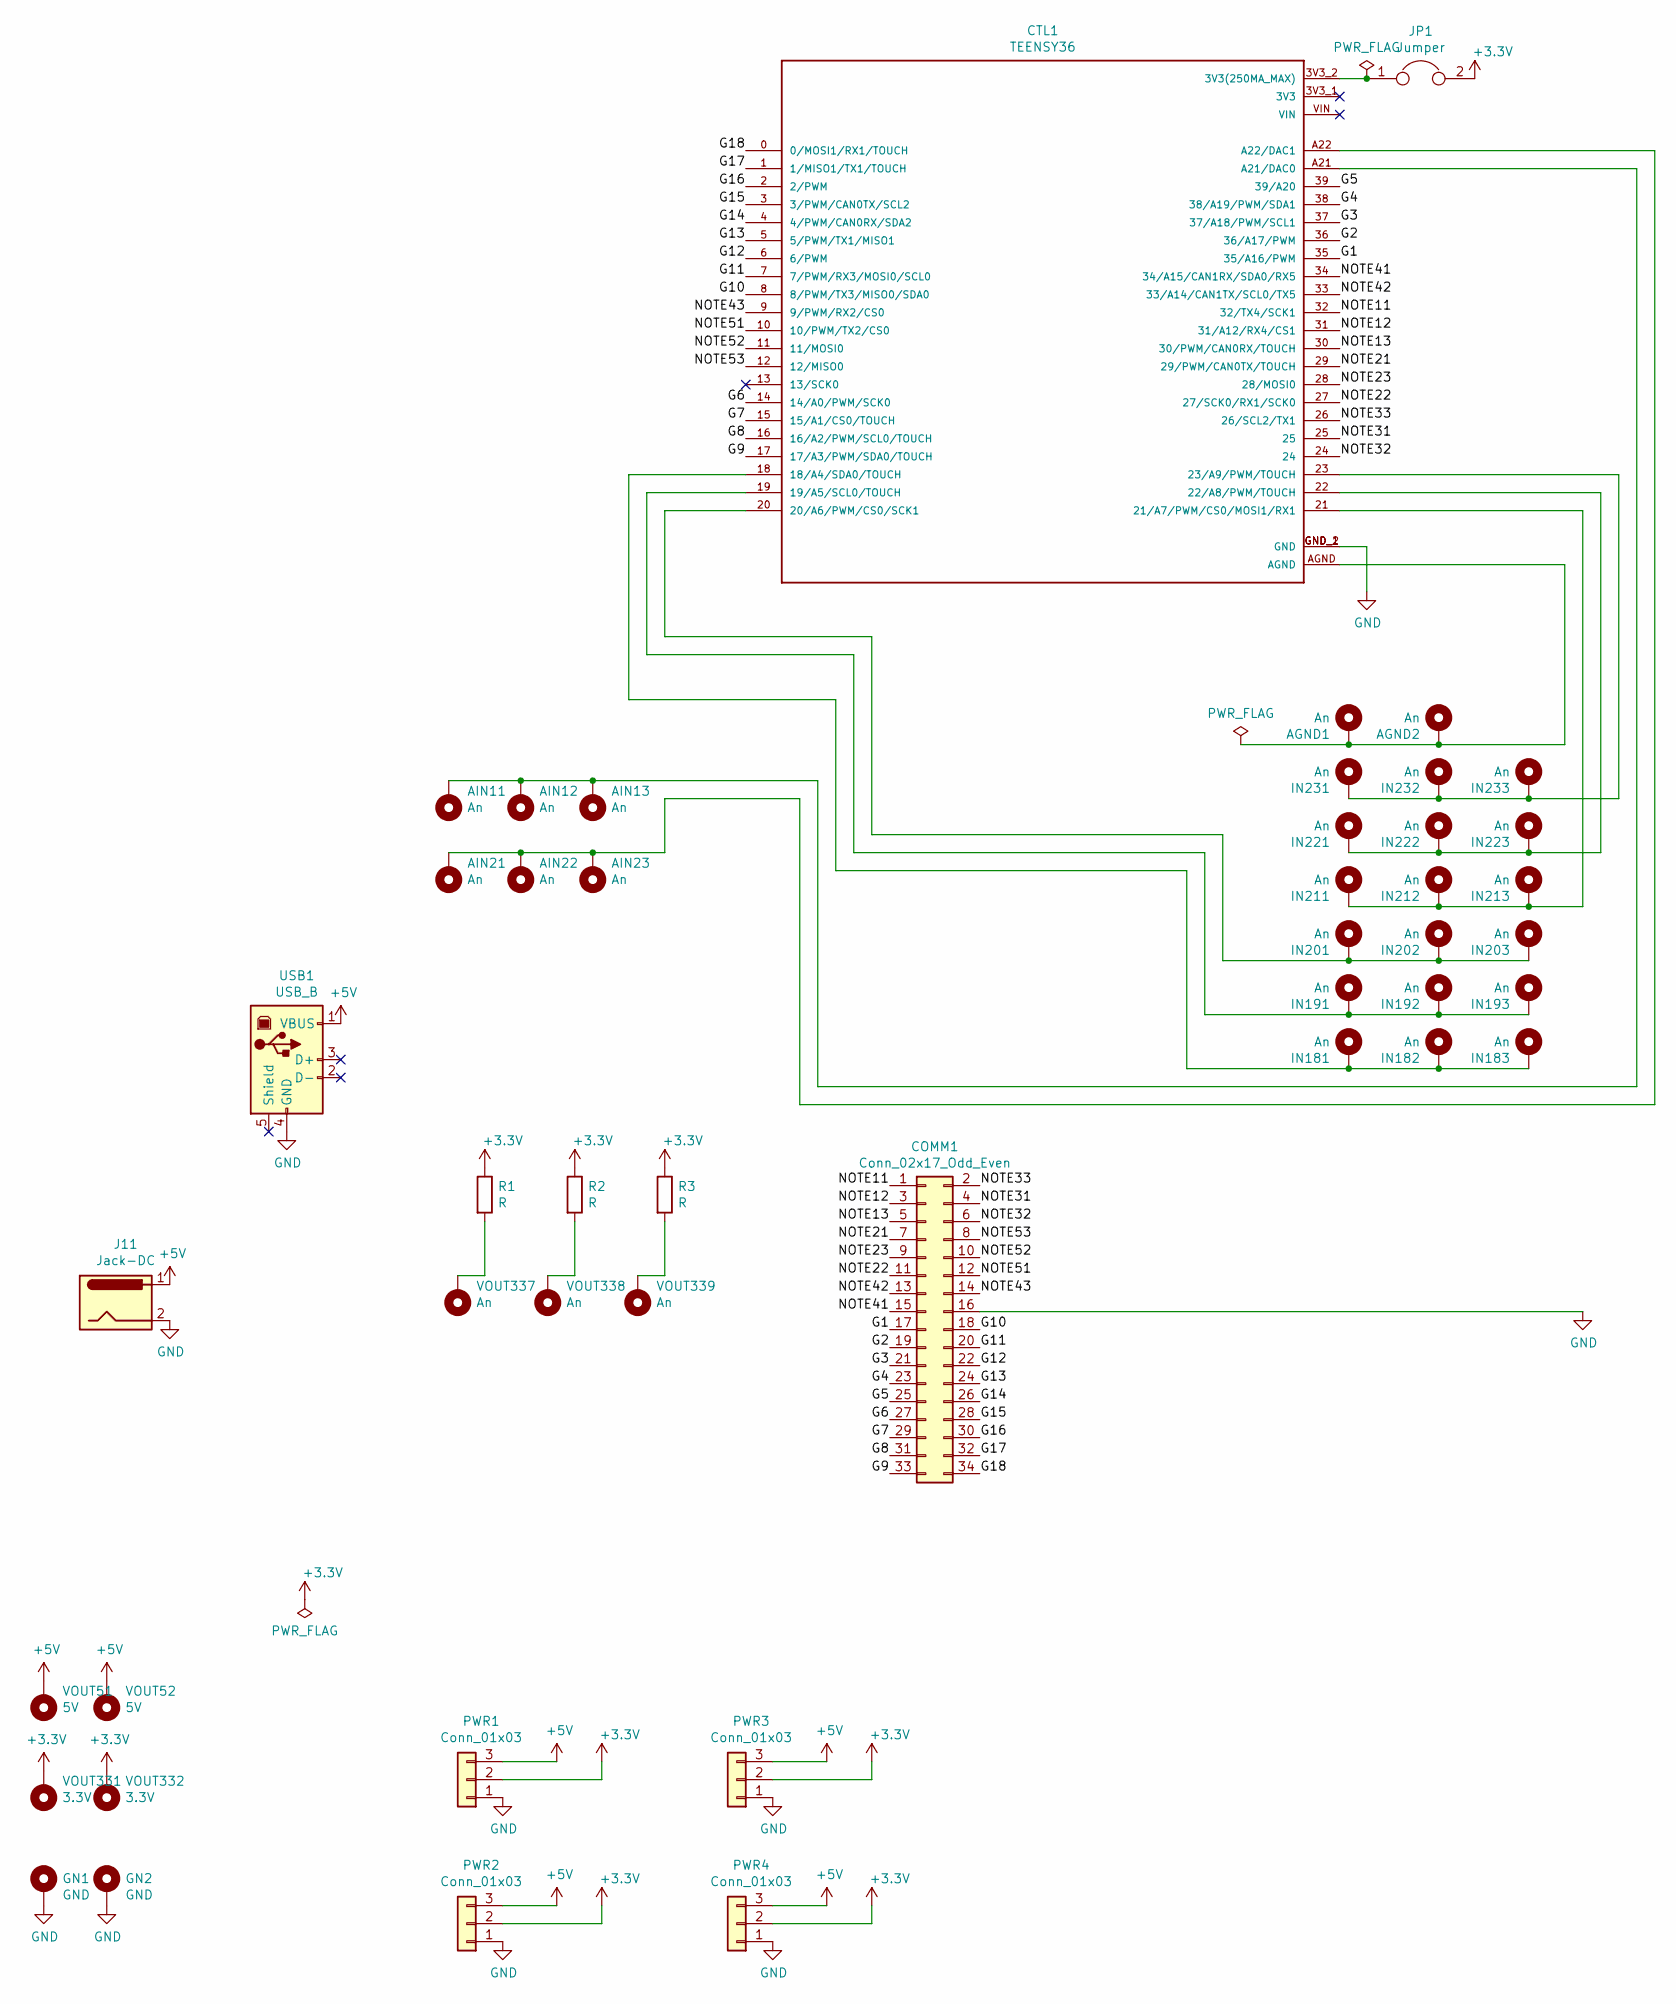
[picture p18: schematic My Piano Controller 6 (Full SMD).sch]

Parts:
AGND1, AGND2: An; SolderWirePad_single_0-8mmDrill
AIN11, AIN12, AIN13, AIN21, AIN22, AIN23: An; SolderWirePad_single_0-8mmDrill
COMM1: Conn_02x17_Odd_Even; Multicomp_MC9A12-3434_2x17x2.54mm_Straight
CTL1: TEENSY36; SPARKFUN_TEENSY36
GN1, GN2: GND; SolderWirePad_single_1mmDrill
IN181, IN182, IN183, IN191, IN192, IN193, IN201, IN202, IN203, IN211, IN212, IN213, IN221, IN222, IN223, IN231, IN232, IN233: An; SolderWirePad_single_0-8mmDrill
J11: Jack-DC; BARREL_JACK
JP1: Jumper; Pin_Header_Straight_1x02_Pitch2.54mm
PWR1, PWR2, PWR3, PWR4: Conn_01x03; JST_XH_B03B-XH-A_03x2.50mm_Straight
R1, R2, R3: R; R_0603_HandSoldering
USB1: USB_B
VOUT51, VOUT52: 5V; SolderWirePad_single_1mmDrill
VOUT331, VOUT332: 3.3V; SolderWirePad_single_1mmDrill
VOUT337, VOUT338, VOUT339: An; SolderWirePad_single_0-8mmDrill

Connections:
+3V3: JP1.2, PWR1.2, PWR2.2, PWR3.2, PWR4.2, R1.1, R2.1, R3.1, VOUT331.1, VOUT332.1
+5V: J11.1, PWR1.3, PWR2.3, PWR3.3, PWR4.3, USB1.1 (VBUS), VOUT51.1, VOUT52.1
/G1: COMM1.17, CTL1.35 (35/A16/PWM)
/G2: COMM1.19, CTL1.36 (36/A17/PWM)
/G3: COMM1.21, CTL1.37 (37/A18/PWM/SCL1)
/G4: COMM1.23, CTL1.38 (38/A19/PWM/SDA1)
/G5: COMM1.25, CTL1.39 (39/A20)
/G6: COMM1.27, CTL1.14 (14/A0/PWM/SCK0)
/G7: COMM1.29, CTL1.15 (15/A1/CS0/TOUCH)
/G8: COMM1.31, CTL1.16 (16/A2/PWM/SCL0/TOUCH)
/G9: COMM1.33, CTL1.17 (17/A3/PWM/SDA0/TOUCH)
/G10: COMM1.18, CTL1.8 (8/PWM/TX3/MISO0/SDA0)
/G11: COMM1.20, CTL1.7 (7/PWM/RX3/MOSI0/SCL0)
/G12: COMM1.22, CTL1.6 (6/PWM)
/G13: COMM1.24, CTL1.5 (5/PWM/TX1/MISO1)
/G14: COMM1.26, CTL1.4 (4/PWM/CAN0RX/SDA2)
/G15: COMM1.28, CTL1.3 (3/PWM/CAN0TX/SCL2)
/G16: COMM1.30, CTL1.2 (2/PWM)
/G17: COMM1.32, CTL1.1 (1/MISO1/TX1/TOUCH)
/G18: COMM1.34, CTL1.0 (0/MOSI1/RX1/TOUCH)
/NOTE11: COMM1.1, CTL1.32 (32/TX4/SCK1)
/NOTE12: COMM1.3, CTL1.31 (31/A12/RX4/CS1)
/NOTE13: COMM1.5, CTL1.30 (30/PWM/CAN0RX/TOUCH)
/NOTE21: COMM1.7, CTL1.29 (29/PWM/CAN0TX/TOUCH)
/NOTE22: COMM1.11, CTL1.27 (27/SCK0/RX1/SCK0)
/NOTE23: COMM1.9, CTL1.28 (28/MOSI0)
/NOTE31: COMM1.4, CTL1.25
/NOTE32: COMM1.6, CTL1.24
/NOTE33: COMM1.2, CTL1.26 (26/SCL2/TX1)
/NOTE41: COMM1.15, CTL1.34 (34/A15/CAN1RX/SDA0/RX5)
/NOTE42: COMM1.13, CTL1.33 (33/A14/CAN1TX/SCL0/TX5)
/NOTE43: COMM1.14, CTL1.9 (9/PWM/RX2/CS0)
/NOTE51: COMM1.12, CTL1.10 (10/PWM/TX2/CS0)
/NOTE52: COMM1.10, CTL1.11 (11/MOSI0)
/NOTE53: COMM1.8, CTL1.12 (12/MISO0)
GND: COMM1.16, CTL1.GND_1 (GND), CTL1.GND_2 (GND), GN1.1, GN2.1, J11.2, PWR1.1, PWR2.1, PWR3.1, PWR4.1, USB1.4 (GND)
unnamed: AGND1.1, AGND2.1, CTL1.AGND
unnamed: AIN11.1, AIN12.1, AIN13.1, CTL1.A21 (A21/DAC0)
unnamed: AIN21.1, AIN22.1, AIN23.1, CTL1.A22 (A22/DAC1)
unnamed: CTL1.3V3_2 (3V3(250MA_MAX)), JP1.1
unnamed: CTL1.18 (18/A4/SDA0/TOUCH), IN181.1, IN182.1, IN183.1
unnamed: CTL1.19 (19/A5/SCL0/TOUCH), IN191.1, IN192.1, IN193.1
unnamed: CTL1.20 (20/A6/PWM/CS0/SCK1), IN201.1, IN202.1, IN203.1
unnamed: CTL1.21 (21/A7/PWM/CS0/MOSI1/RX1), IN211.1, IN212.1, IN213.1
unnamed: CTL1.22 (22/A8/PWM/TOUCH), IN221.1, IN222.1, IN223.1
unnamed: CTL1.23 (23/A9/PWM/TOUCH), IN231.1, IN232.1, IN233.1
unnamed: R1.2, VOUT337.1
unnamed: R2.2, VOUT338.1
unnamed: R3.2, VOUT339.1

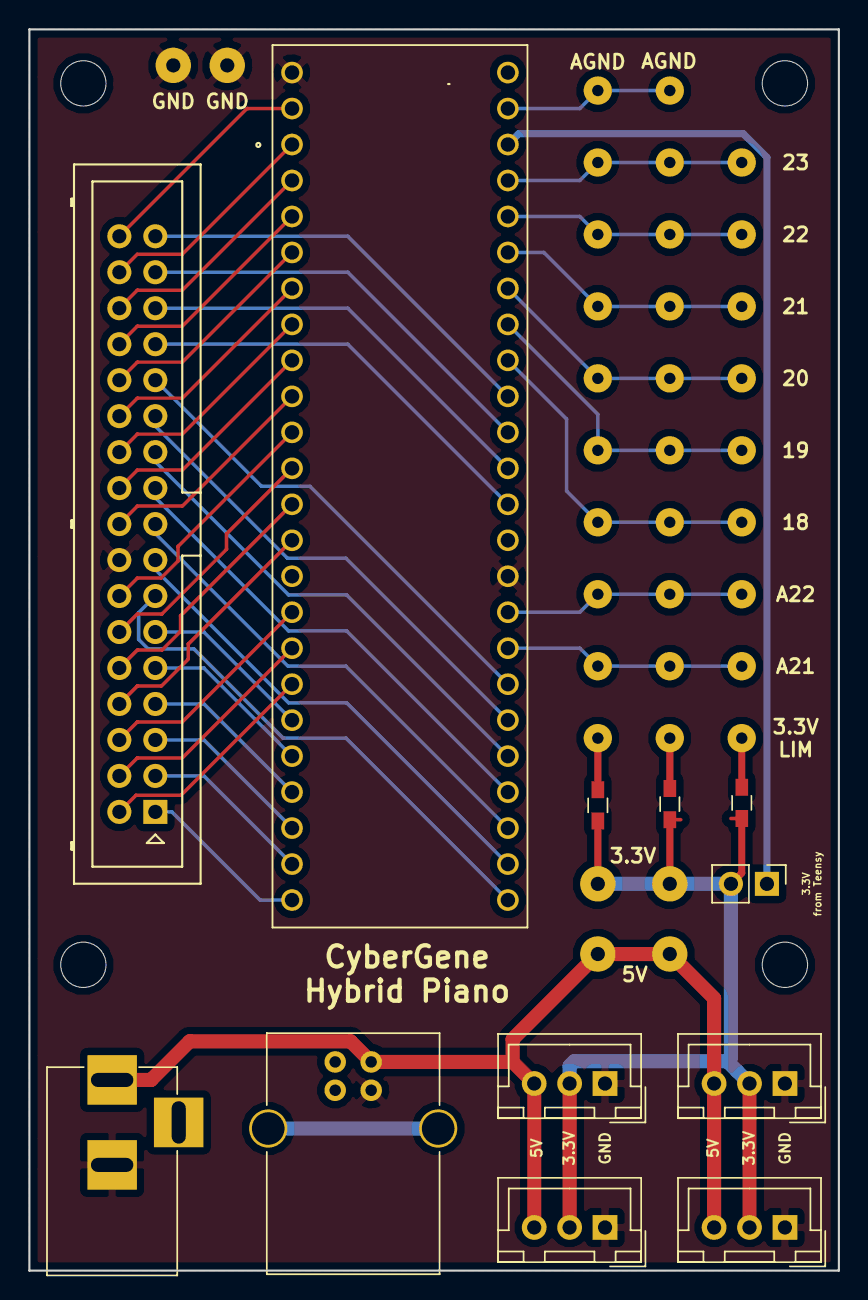
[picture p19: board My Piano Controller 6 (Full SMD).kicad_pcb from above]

Board: 2 copper layers, 57.1 x 87.6 mm, 51 parts (0 on the bottom side), 49 nets.

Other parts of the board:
HOLE1, HOLE2, HOLE3, HOLE4: MountingHole_3.2mm_M3

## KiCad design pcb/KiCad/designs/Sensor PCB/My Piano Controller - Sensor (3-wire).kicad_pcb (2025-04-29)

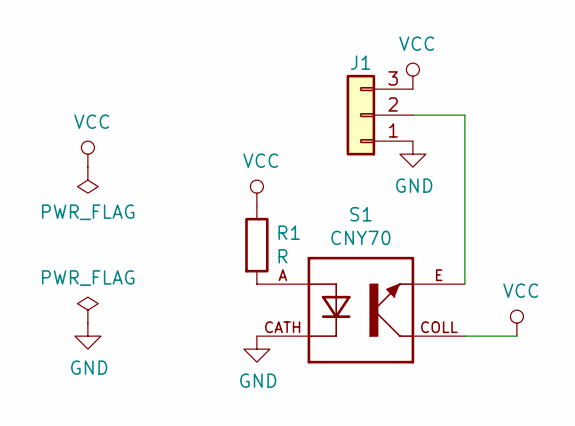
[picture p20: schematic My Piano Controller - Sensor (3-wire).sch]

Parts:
J1: Conn_01x03; Socket_Strip_Straight_1x03_Pitch2.54mm
R1: R; R_0603_HandSoldering
S1: CNY70; DIPS254W50P254L710H600Q4

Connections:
GND: J1.1, S1.CATH
unnamed: J1.2, S1.E
unnamed: R1.2, S1.A
VCC: J1.3, R1.1, S1.COLL

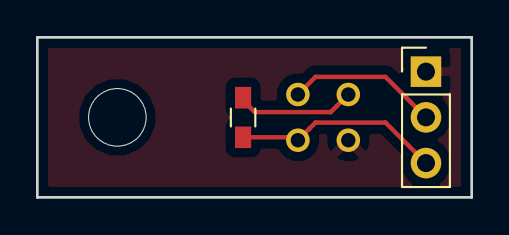
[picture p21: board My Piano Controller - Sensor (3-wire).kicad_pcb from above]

Board: 2 copper layers, 24.1 x 8.9 mm, 3 parts (1 on the bottom side), 4 nets.

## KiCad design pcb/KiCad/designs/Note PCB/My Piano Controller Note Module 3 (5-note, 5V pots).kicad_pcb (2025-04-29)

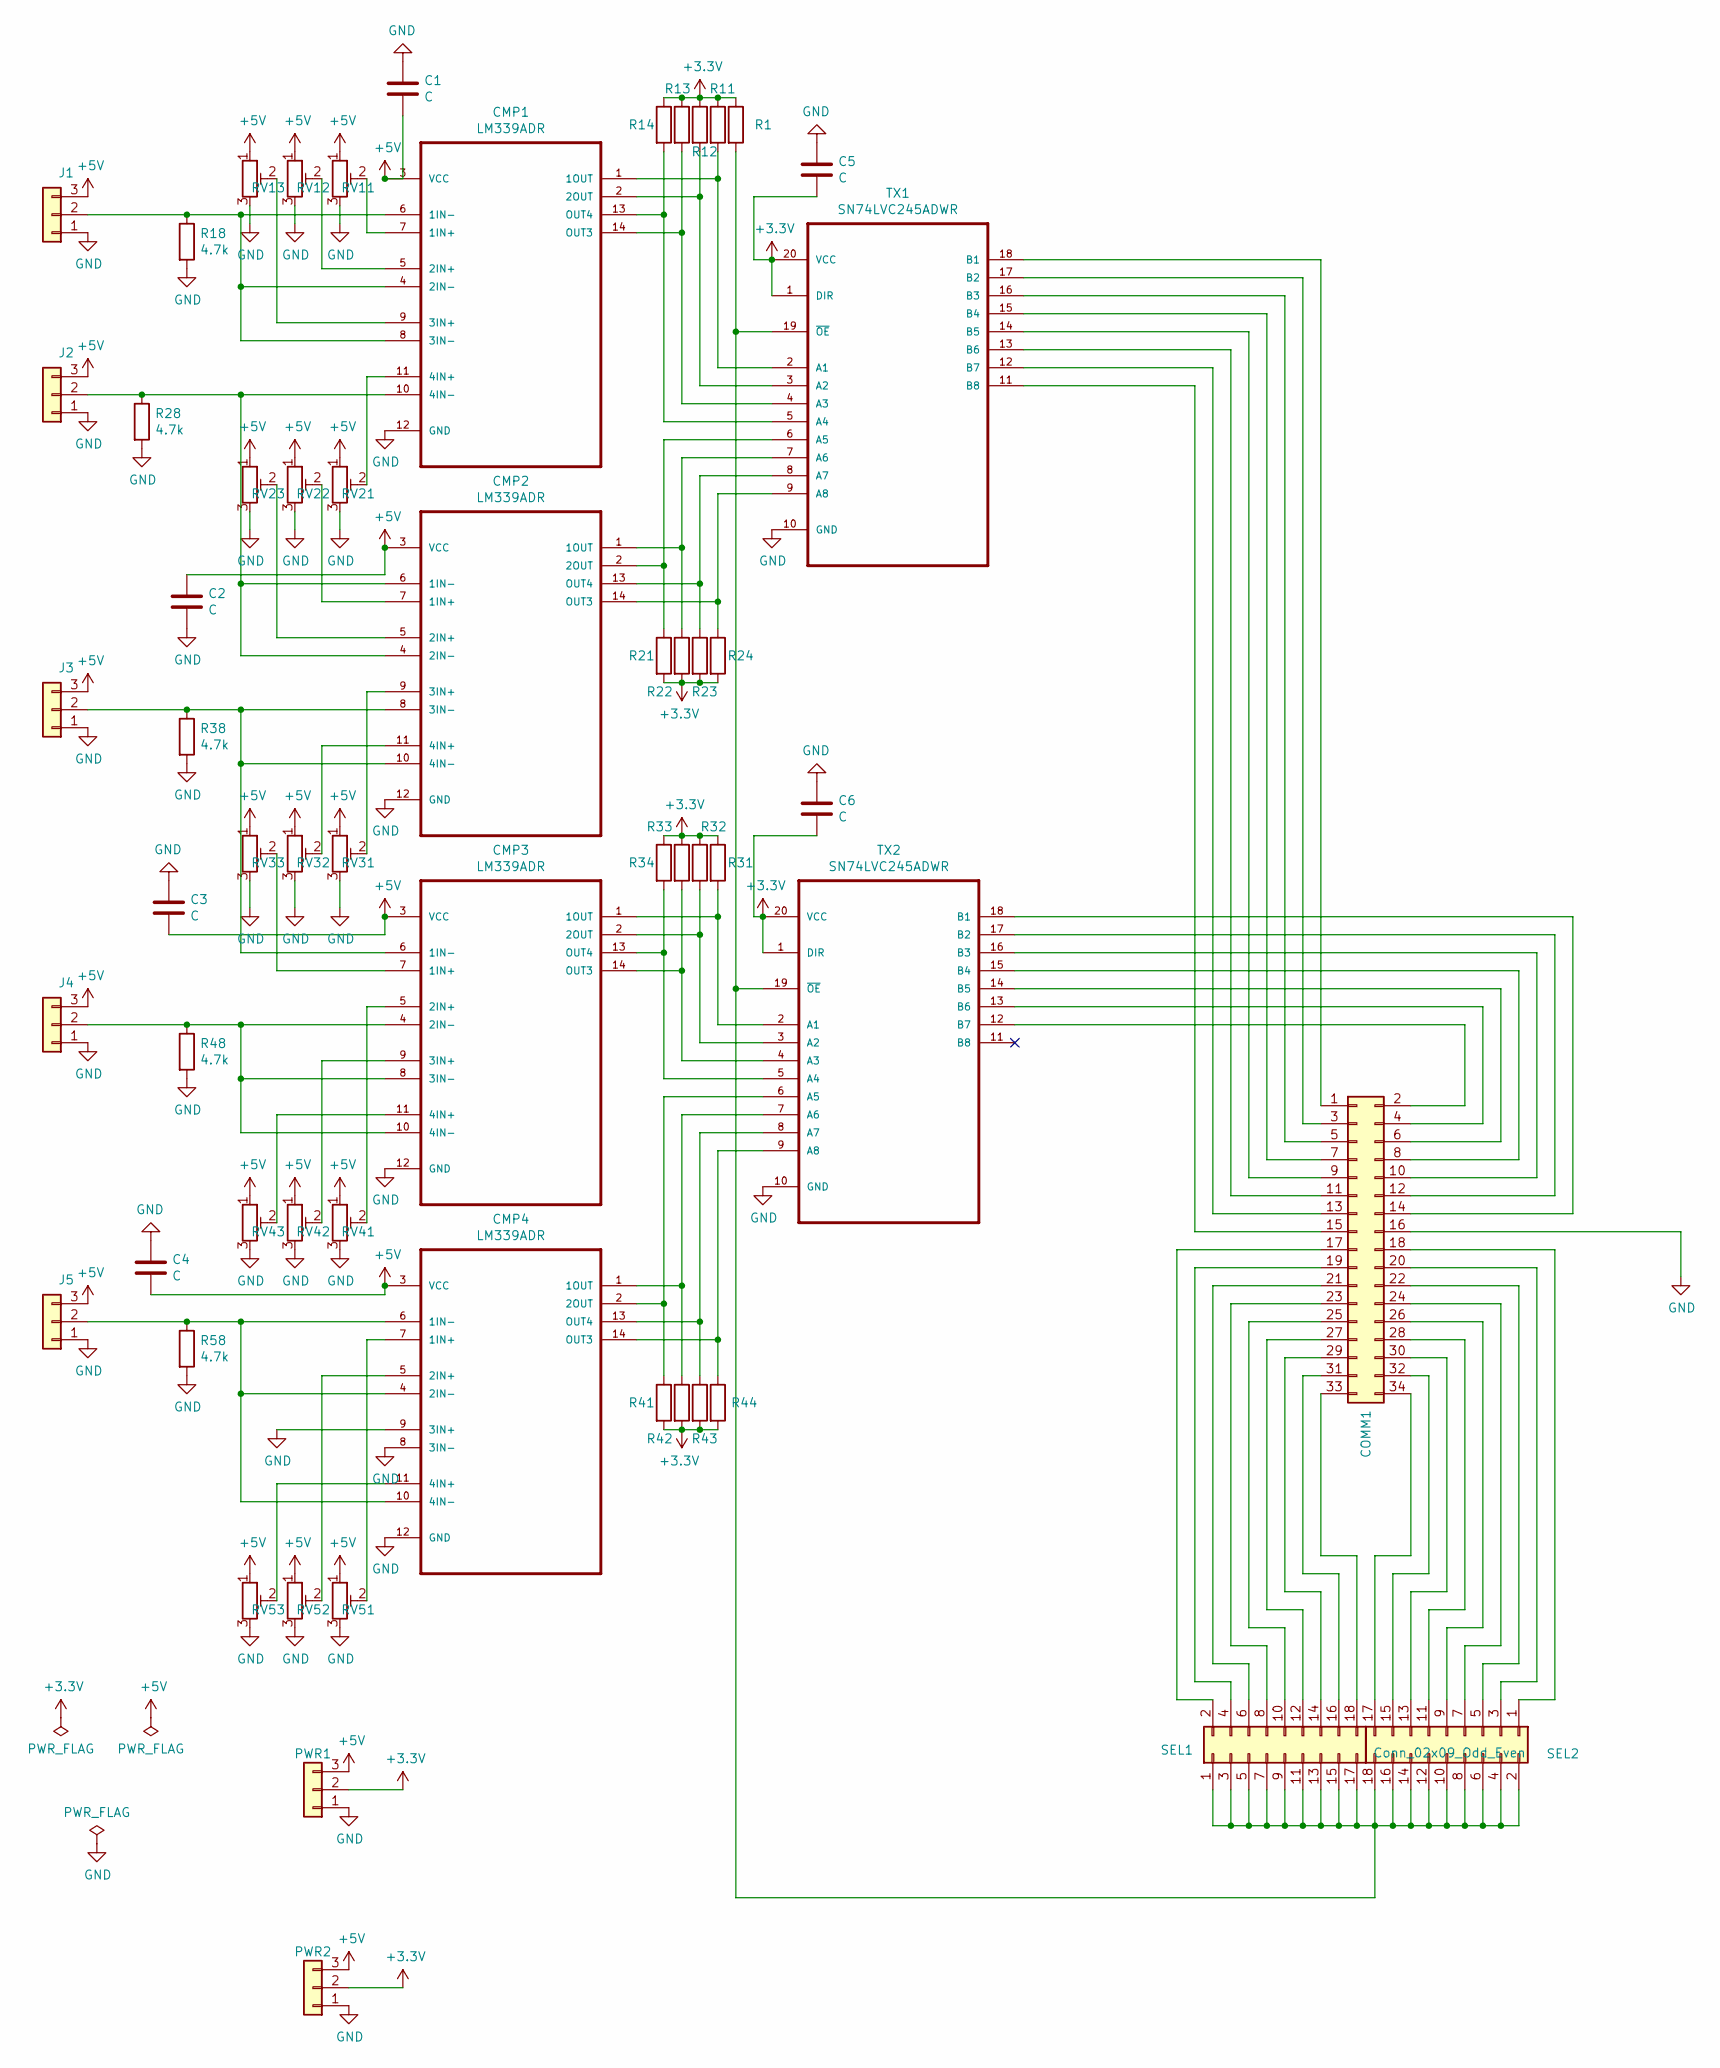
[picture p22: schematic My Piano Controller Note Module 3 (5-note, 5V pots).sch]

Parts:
C1, C2, C3, C4, C5, C6: C; C_0603_HandSoldering
CMP1, CMP2, CMP3, CMP4: LM339ADR; SOIC127P600X175-14N
COMM1: Conn_02x17_Odd_Even; Multicomp_MC9A12-3434_2x17x2.54mm_Straight
J1, J2, J3, J4, J5: Conn_01x03; Pin_Header_Straight_1x03_Pitch2.54mm
PWR1, PWR2: Conn_01x03; JST_XH_B03B-XH-A_03x2.50mm_Straight
R1, R11, R12, R13, R14, R21, R22, R23, R24, R31, R32, R33, R34, R41, R42, R43, R44: R; R_0603_HandSoldering
R18, R28, R38, R48, R58: 4.7k; R_0603_HandSoldering
RV11, RV12, RV13, RV21, RV22, RV23, RV31, RV32, RV33, RV41, RV42, RV43, RV51, RV52, RV53: R_POT_TRIM; Potentiometer_Trimmer_Bourns_3296W
SEL1, SEL2: Conn_02x09_Odd_Even; Pin_Header_Straight_2x09_Pitch2.54mm
TX1, TX2: SN74LVC245ADWR; SOIC127P1030X265-20N

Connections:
+3V3: C5.2, C6.2, PWR1.2, PWR2.2, R1.1, R11.1, R12.1, R13.1, R14.1, R21.2, R22.2, R23.2, R24.2, R31.1, R32.1, R33.1, R34.1, R41.2, R42.2, R43.2, R44.2, TX1.1 (DIR), TX1.20 (VCC), TX2.1 (DIR), TX2.20 (VCC)
+5V: C1.2, C2.1, C3.2, C4.2, CMP1.3 (VCC), CMP2.3 (VCC), CMP3.3 (VCC), CMP4.3 (VCC), J1.3, J2.3, J3.3, J4.3, J5.3, PWR1.3, PWR2.3, RV11.1, RV12.1, RV13.1, RV21.1, RV22.1, RV23.1, RV31.1, RV32.1, RV33.1, RV41.1, RV42.1, RV43.1, RV51.1, RV52.1, RV53.1
GND: C1.1, C2.2, C3.1, C4.1, C5.1, C6.1, CMP1.12 (GND), CMP2.12 (GND), CMP3.12 (GND), CMP4.8 (3IN-), CMP4.9 (3IN+), CMP4.12 (GND), COMM1.16, J1.1, J2.1, J3.1, J4.1, J5.1, PWR1.1, PWR2.1, R18.2, R28.2, R38.2, R48.2, R58.2, RV11.3, RV12.3, RV13.3, RV21.3, RV22.3, RV23.3, RV31.3, RV32.3, RV33.3, RV41.3, RV42.3, RV43.3, RV51.3, RV52.3, RV53.3, TX1.10 (GND), TX2.10 (GND)
unnamed: CMP1.1 (1OUT), R11.2, TX1.2 (A1)
unnamed: CMP1.2 (2OUT), R12.2, TX1.3 (A2)
unnamed: CMP1.4 (2IN-), CMP1.6 (1IN-), CMP1.8 (3IN-), J1.2, R18.1
unnamed: CMP1.5 (2IN+), RV12.2
unnamed: CMP1.7 (1IN+), RV11.2
unnamed: CMP1.9 (3IN+), RV13.2
unnamed: CMP1.10 (4IN-), CMP2.4 (2IN-), CMP2.6 (1IN-), J2.2, R28.1
unnamed: CMP1.11 (4IN+), RV21.2
unnamed: CMP1.13 (OUT4), R14.2, TX1.5 (A4)
unnamed: CMP1.14 (OUT3), R13.2, TX1.4 (A3)
unnamed: CMP2.1 (1OUT), R22.1, TX1.7 (A6)
unnamed: CMP2.2 (2OUT), R21.1, TX1.6 (A5)
unnamed: CMP2.5 (2IN+), RV23.2
unnamed: CMP2.7 (1IN+), RV22.2
unnamed: CMP2.9 (3IN+), RV31.2
unnamed: CMP2.8 (3IN-), CMP2.10 (4IN-), CMP3.6 (1IN-), J3.2, R38.1
unnamed: CMP2.11 (4IN+), RV32.2
unnamed: CMP2.13 (OUT4), R23.1, TX1.8 (A7)
unnamed: CMP2.14 (OUT3), R24.1, TX1.9 (A8)
unnamed: CMP3.1 (1OUT), R31.2, TX2.2 (A1)
unnamed: CMP3.2 (2OUT), R32.2, TX2.3 (A2)
unnamed: CMP3.5 (2IN+), RV41.2
unnamed: CMP3.7 (1IN+), RV33.2
unnamed: CMP3.9 (3IN+), RV42.2
unnamed: CMP3.4 (2IN-), CMP3.8 (3IN-), CMP3.10 (4IN-), J4.2, R48.1
unnamed: CMP3.11 (4IN+), RV43.2
unnamed: CMP3.13 (OUT4), R34.2, TX2.5 (A4)
unnamed: CMP3.14 (OUT3), R33.2, TX2.4 (A3)
unnamed: CMP4.1 (1OUT), R42.1, TX2.7 (A6)
unnamed: CMP4.2 (2OUT), R41.1, TX2.6 (A5)
unnamed: CMP4.5 (2IN+), RV52.2
unnamed: CMP4.7 (1IN+), RV51.2
unnamed: CMP4.4 (2IN-), CMP4.6 (1IN-), CMP4.10 (4IN-), J5.2, R58.1
unnamed: CMP4.11 (4IN+), RV53.2
unnamed: CMP4.13 (OUT4), R43.1, TX2.8 (A7)
unnamed: CMP4.14 (OUT3), R44.1, TX2.9 (A8)
unnamed: COMM1.1, TX1.18 (B1)
unnamed: COMM1.2, TX2.12 (B7)
unnamed: COMM1.3, TX1.17 (B2)
unnamed: COMM1.4, TX2.13 (B6)
unnamed: COMM1.5, TX1.16 (B3)
unnamed: COMM1.6, TX2.14 (B5)
unnamed: COMM1.7, TX1.15 (B4)
unnamed: COMM1.8, TX2.15 (B4)
unnamed: COMM1.9, TX1.14 (B5)
unnamed: COMM1.10, TX2.16 (B3)
unnamed: COMM1.11, TX1.13 (B6)
unnamed: COMM1.12, TX2.17 (B2)
unnamed: COMM1.13, TX1.12 (B7)
unnamed: COMM1.14, TX2.18 (B1)
unnamed: COMM1.15, TX1.11 (B8)
unnamed: COMM1.17, SEL1.2
unnamed: COMM1.18, SEL2.1
unnamed: COMM1.19, SEL1.4
unnamed: COMM1.20, SEL2.3
unnamed: COMM1.21, SEL1.6
unnamed: COMM1.22, SEL2.5
unnamed: COMM1.23, SEL1.8
unnamed: COMM1.24, SEL2.7
unnamed: COMM1.25, SEL1.10
unnamed: COMM1.26, SEL2.9
unnamed: COMM1.27, SEL1.12
unnamed: COMM1.28, SEL2.11
unnamed: COMM1.29, SEL1.14
unnamed: COMM1.30, SEL2.13
unnamed: COMM1.31, SEL1.16
unnamed: COMM1.32, SEL2.15
unnamed: COMM1.33, SEL1.18
unnamed: COMM1.34, SEL2.17
unnamed: R1.2, SEL1.1, SEL1.3, SEL1.5, SEL1.7, SEL1.9, SEL1.11, SEL1.13, SEL1.15, SEL1.17, SEL2.2, SEL2.4, SEL2.6, SEL2.8, SEL2.10, SEL2.12, SEL2.14, SEL2.16, SEL2.18, TX1.19 (~OE), TX2.19 (~OE)

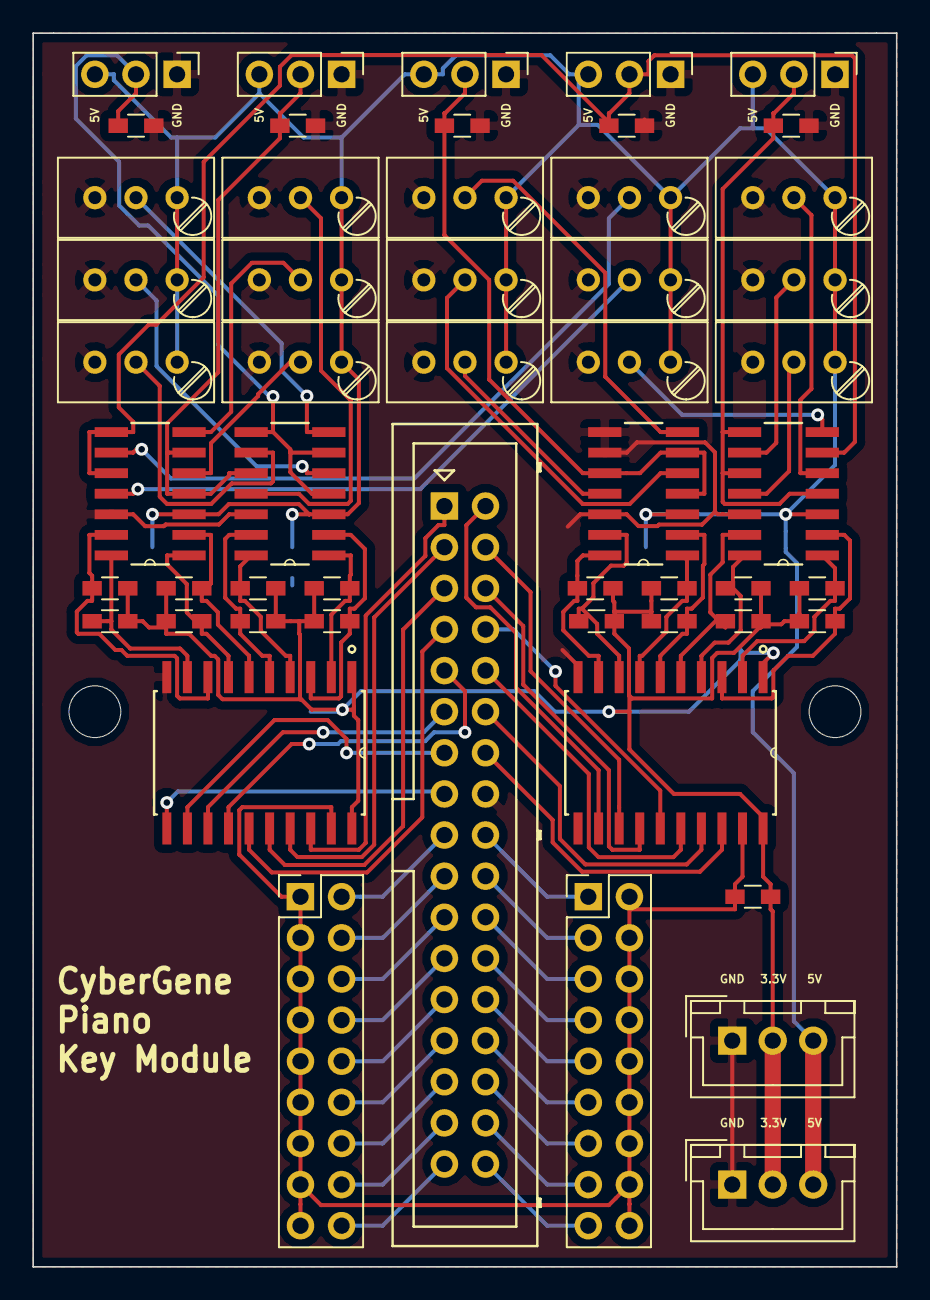
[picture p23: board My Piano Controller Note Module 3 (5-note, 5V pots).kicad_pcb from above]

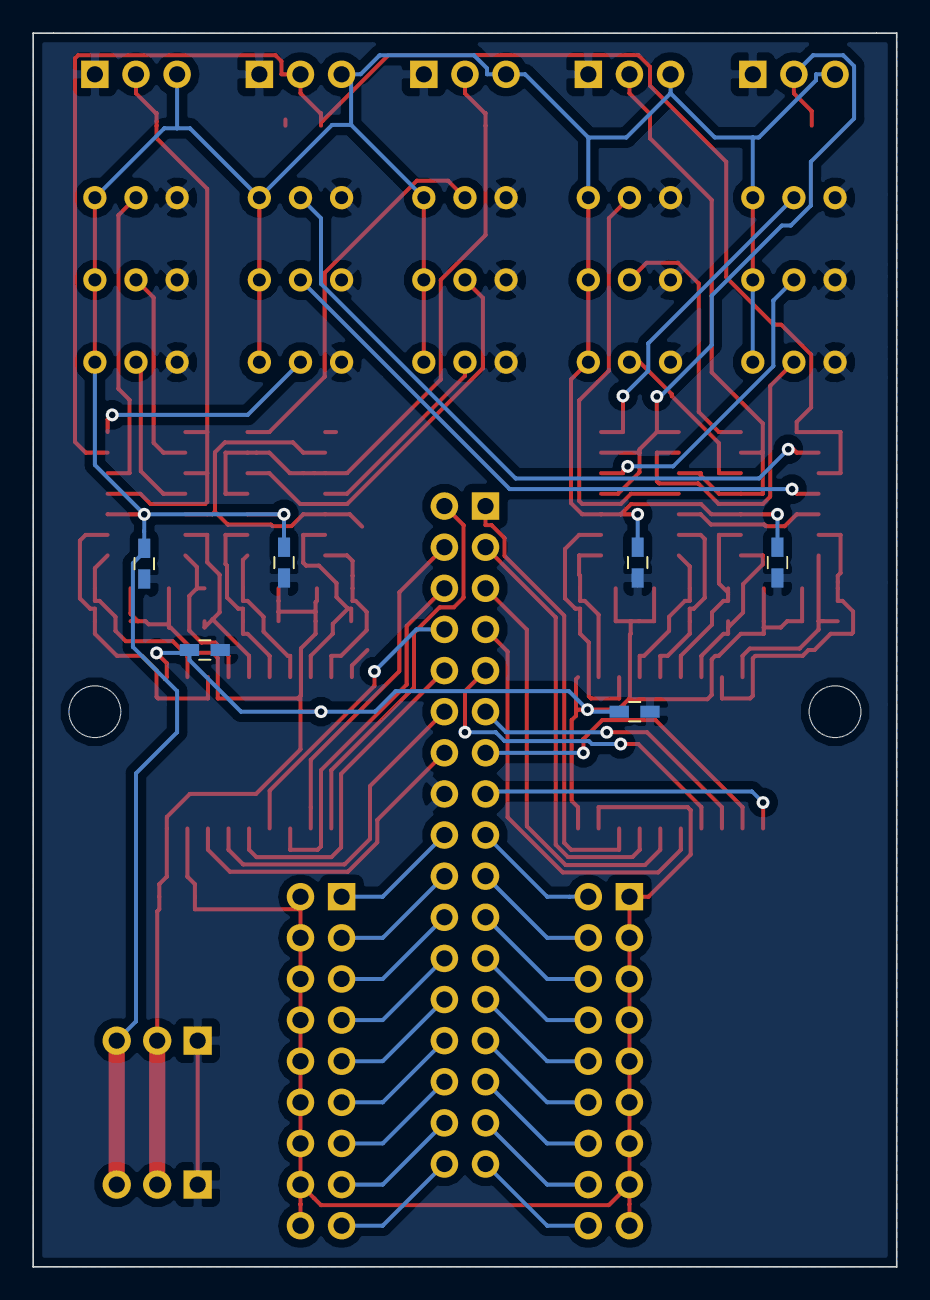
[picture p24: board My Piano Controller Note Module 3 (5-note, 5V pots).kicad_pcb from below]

Board: 2 copper layers, 53.3 x 76.2 mm, 61 parts (6 on the bottom side), 73 nets.

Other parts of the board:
HOLE1, HOLE2: MountingHole_3.2mm_M3

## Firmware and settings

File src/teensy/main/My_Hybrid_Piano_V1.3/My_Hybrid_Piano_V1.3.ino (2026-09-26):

/**
 * CyberGene's DIY Hybrid Piano Controller - FIRMWARE v1.3 (MASTER REFERENCE)
 * TARGET: Teensy 4.1 @ 600 MHz
 * -------------------------------------------------------------
 * COMPILER OPTIMIZATION FLAGS (PlatformIO/Arduino IDE):
 * -------------------------------------------------------------
 * Add these to platformio.ini or Arduino IDE compiler settings:
 *
 * build_flags =
 *     -O3                    ; Maximum optimization (speed priority)
 *     -mcpu=cortex-m7        ; Target ARM Cortex-M7 architecture
 *     -mfloat-abi=hard       ; Use hardware FPU for floating-point ops
 *
 * These flags enable:
 * - Aggressive inlining and loop optimization
 * - SIMD instructions where applicable
 * - Hardware floating-point for velocity calculations
 * - Branch prediction optimization
 *
 * -------------------------------------------------------------
 * PERFORMANCE METRICS:
 * -------------------------------------------------------------
 * - Measured by CyberGene with V1.2: full keyboard scan ~8.9µs
 *   (~0.5µs per group, ~112 kHz scan rate), velocity error at
 *   MIDI 127 under 1 step.
 * - This version (not yet measured): estimated ~3-5µs per full
 *   scan on Teensy 4.1 (~3.6µs typical), ~10-15µs on Teensy 3.6
 *   @ 256 MHz, from emulating the compiled loop() and published
 *   GPIO access times. Each group still gets >= 100ns to settle.
 * -------------------------------------------------------------
 * PHYSICS & DETECTION PRINCIPLE (CNY70 + Comparators):
 * -------------------------------------------------------------
 * This controller detects hammer position using reflective optical
 * proximity sensors (CNY70) paired with voltage comparators.
 *
 * * THE SENSOR LOGIC (Active LOW):
 * 1. As the hammer rises, it reflects IR light back into the CNY70.
 * 2. When the hammer gets CLOSER than a specific distance (set by a
 * trimpot threshold on the PCB), the comparator switches output to LOW.
 * 3. Therefore:
 * - HIGH (3.3V) = Hammer is FAR (Reflector out of range).
 * - LOW  (0V)   = Hammer is NEAR (Reflector within range).
 *
 * * THE CHECK POINTS (Sequential Activation):
 * As the hammer travels upward from Rest to Strike, it sequentially
 * enters the detection range of three sensors. We rely on this sequence
 * to determine direction and velocity.
 *
 * 1. DAMPER POINT (Mid-Travel):
 * - Physical: The point where the damper would lift off the string.
 * - Logic: First sensor to trigger (LOW) as hammer rises.
 * Last sensor to release (HIGH) as hammer falls.
 *
 * 2. ESCAPEMENT POINT (Upper Travel):
 * - Physical: Approx 2-3mm below the stop rail.
 * - Logic: Activates second. This is our "Start Line" for velocity.
 *
 * 3. STRIKE POINT (Top / Velocity End):
 * - Physical: Slightly below the stop rail (e.g. 0.5mm gap).
 * We place it slightly below to ensure the hardware detects the
 * hammer *before* it physically stops dead against the felt.
 * - Logic: Activates last. This is our "Finish Line".
 * -------------------------------------------------------------
 */

#include <ADC.h>

// Forced inline: the pin numbers must reach digitalReadFast() as compile-time constants
// (otherwise every read goes through a pin lookup table, doubling the scan time), and
// the per-key logic must not pay a function call per key.
struct InputSnapshot;
static inline __attribute__((always_inline)) void readGroupInputs(InputSnapshot &s);
static inline __attribute__((always_inline)) void processGroup(int g, const InputSnapshot &s);
static inline __attribute__((always_inline)) void checkHammerState(byte note, byte curve, bool atStrike, bool atEscap, bool atDamper);
static inline __attribute__((always_inline)) void waitCyclesSince(uint32_t start, uint32_t cycles);

// =============================================================
// --- USER CONFIGURATION --------------------------------------
// =============================================================

// PIANO SIZE: 85 (A0-A7) or 88 (A0-C8)
#define PIANO_SIZE 85

/**
 * FAULTY CABLE LINE WORKAROUND:
 * -------------------------------------------------------------
 * A hardware abstraction to skip ONE specific faulty line on the ribbon cable.
 * * IMPORTANT CONSTRAINTS:
 * 1. This is ONLY available for 85-key pianos (which leave 1 line unused).
 * 2. It can only handle ONE faulty line.
 * * SETTING:
 * * 0   : NORMAL OPERATION (All lines functional).
 * * 1-18: The physical index of the faulty line to skip.
 * (e.g., 16 = Skip physical Line 16).
 */
#define FAULTY_LINE 16

/**
 * MATRIX SETTLING TIME (Nanoseconds):
 * -------------------------------------------------------------
 * Wait between ENABLING a group and reading its 15 lines.
 * * HARDWARE CONTEXT:
 * - Groups use SN74LVC245A Transceivers (Active Push-Pull).
 * - Shared 1.5m IDC ribbon cable with 17-18 connectors (stubs).
 * * WHY THE DELAY IS NEEDED:
 * The newly enabled transceiver must drive the long cable to a clean level;
 * reflections from the connector stubs take several round trips to die out.
 * Reading too early gives stale or wrong levels ("ghost notes").
 * * TUNING: V1.2 worked with ~40-110ns (4 dummy reads); 100ns adds margin.
 * Increase if ghosting occurs.
 * * COST: usually none. The previous group is processed while this one settles
 * (see loop()); the wait only covers whatever part of this time is left over.
 */
#define MATRIX_SETTLING_DELAY_NS 100

/**
 * MATRIX DEAD TIME (Nanoseconds):
 * -------------------------------------------------------------
 * Gap between DISABLING one group and ENABLING the next, so two transceivers
 * never drive the shared lines at the same time. The SN74LVC245A needs up to
 * ~8ns to release its outputs (tPHZ/tPLZ at 3.3V); 20ns covers that plus skew.
 */
#define MATRIX_DEAD_TIME_NS 20

// Both waits in CPU cycles, computed at compile time (F_CPU is the configured CPU clock).
#define NS_TO_CYCLES(ns) ((uint32_t)(((uint64_t)F_CPU * (ns) + 999999999ULL) / 1000000000ULL))
#define MATRIX_SETTLING_CYCLES NS_TO_CYCLES(MATRIX_SETTLING_DELAY_NS)
#define MATRIX_DEAD_TIME_CYCLES NS_TO_CYCLES(MATRIX_DEAD_TIME_NS)

// PEDAL SCAN INTERVAL:
// 5ms = 200Hz at most, and only while the pedal moves (see the noise gate in processPedal).
// Limits CC64 traffic while keeping pedal latency low: pedalling is timed against
// key releases, so e.g. a 20ms interval (10ms average delay) is noticeable in legato pedalling.
#define PEDAL_SCAN_INTERVAL_MS 5

// =============================================================

// --- CHECK POINT PIN DEFINITIONS ---
// Naming corresponds to the physical location of the Check Point.
#define N1_STRIKE   32  // Point 1: Closest proximity (Top)
#define N1_ESCAP    31  // Point 2: Medium proximity
#define N1_DAMPER   30  // Point 3: Far proximity (Middle)

#define N2_STRIKE   29
#define N2_ESCAP    27
#define N2_DAMPER   28

#define N3_STRIKE   25
#define N3_ESCAP    24
#define N3_DAMPER   26

#define N4_STRIKE   34
#define N4_ESCAP    33
#define N4_DAMPER   9

#define N5_STRIKE   10
#define N5_ESCAP    11
#define N5_DAMPER   12

// --- INPUT PORT SNAPSHOT ---
// The 15 check point pins sit on a few 32-bit GPIO port registers (which ones is taken
// from the Teensy core's CORE_PINn_PINREG / CORE_PINn_BITMASK). Reading those registers
// once per group captures the whole group at one instant with a few reads instead of 15,
// so it can be processed later, while the next group settles (see loop()).
#if defined(__IMXRT1062__)
  #define INPUT_PORTS(X) X(GPIO6_PSR) X(GPIO7_PSR) X(GPIO8_PSR) X(GPIO9_PSR)
  #define INPUT_PORT_COUNT 4
#else
  #define INPUT_PORTS(X) X(GPIOA_PDIR) X(GPIOB_PDIR) X(GPIOC_PDIR) X(GPIOD_PDIR) X(GPIOE_PDIR)
  #define INPUT_PORT_COUNT 5
#endif

struct InputSnapshot { uint32_t port[INPUT_PORT_COUNT]; };

#define PINREG_ADDR(pin) PINREG_ADDR_(pin)
#define PINREG_ADDR_(pin) ((const volatile void *)&CORE_PIN##pin##_PINREG)
#define PIN_BITMASK(pin) PIN_BITMASK_(pin)
#define PIN_BITMASK_(pin) (CORE_PIN##pin##_BITMASK)

// All address comparisons below are between constants and fold away at compile time.
static inline __attribute__((always_inline)) bool isCheckPointPort(const volatile void *reg) {
  return reg == PINREG_ADDR(N1_STRIKE) || reg == PINREG_ADDR(N1_ESCAP) || reg == PINREG_ADDR(N1_DAMPER)
      || reg == PINREG_ADDR(N2_STRIKE) || reg == PINREG_ADDR(N2_ESCAP) || reg == PINREG_ADDR(N2_DAMPER)
      || reg == PINREG_ADDR(N3_STRIKE) || reg == PINREG_ADDR(N3_ESCAP) || reg == PINREG_ADDR(N3_DAMPER)
      || reg == PINREG_ADDR(N4_STRIKE) || reg == PINREG_ADDR(N4_ESCAP) || reg == PINREG_ADDR(N4_DAMPER)
      || reg == PINREG_ADDR(N5_STRIKE) || reg == PINREG_ADDR(N5_ESCAP) || reg == PINREG_ADDR(N5_DAMPER);
}

// Index of a port register in the snapshot, or -1 if it is not one of INPUT_PORTS.
static inline __attribute__((always_inline)) int snapshotIndex(const volatile void *reg) {
  int i = 0;
  #define SNAPSHOT_INDEX(r) if (reg == (const volatile void *)&(r)) return i; i++;
  INPUT_PORTS(SNAPSHOT_INDEX)
  #undef SNAPSHOT_INDEX
  return -1;
}

// Build-time check: every check point pin must be on a snapshotted port, otherwise its
// input would silently read as "hammer at rest". If this fails, the build stops with an
// undefined reference to the function below; add the missing port to INPUT_PORTS.
void ERROR_check_point_pin_not_on_an_INPUT_PORTS_register();
#define CHECK_ON_INPUT_PORT(pin) \
  if (snapshotIndex(PINREG_ADDR(pin)) < 0) ERROR_check_point_pin_not_on_an_INPUT_PORTS_register();

// True when the hammer is within check point `pin` (comparators are active LOW).
#define AT_POINT(s, pin) (((s).port[snapshotIndex(PINREG_ADDR(pin))] & PIN_BITMASK(pin)) == 0)

// --- PERIPHERALS ---
#define HALF_PEDAL  A16 // Connected to Kawai 10H (Pin 40 on T4.1)
#define LED         13

// =============================================================
// --- VELOCITY CURVE & PHYSICS CONSTANTS ----------------------
// =============================================================

/**
 * VEL_MAP_LENGTH:
 * The maximum time (in microseconds) we allow for the hammer to travel
 * between Escapement and Strike.
 * - 12187us (12ms) is roughly the slowest a hammer can move and still
 * create a sound. Anything slower is considered a silent press.
 */
#define VEL_MAP_LENGTH 12187

/**
 * VEL_DISTANCE_FACTOR:
 * A physics constant representing the effective distance between the
 * Escapement Point and Strike Point (approx 2mm), normalized for the
 * logarithmic formula. It scales the raw time (t) into a dimensionless
 * velocity ratio.
 */
#define VEL_DISTANCE_FACTOR 1500.0

/**
 * VEL_LOG_MULTIPLIER:
 * This scales the result of the log() function to fit the MIDI 1-127 range.
 * Formula: MIDI = Multiplier * log(Distance / Time)
 * Increasing this makes the velocity curve "steeper" (more dynamic range).
 */
#define VEL_LOG_MULTIPLIER 100.0

/**
 * VEL_ADDITION:
 * An offset added to the result to shift the curve up or down.
 * This ensures that even the lightest possible touch (max time) still
 * maps to at least MIDI velocity 1, rather than 0 or negative.
 */
#define VEL_ADDITION 57.96

/**
 * VELOCITY_MAP_STRETCH (Grading Factor):
 * Simulates "Graded Hammer Action" found in acoustic grands.
 * - In a real piano, bass hammers are heavier/slower than treble hammers
 * for the same input force.
 * - 0.4 spreads the VEL_GRADE_STEPS curves from a multiplier of 1.2
 * (curve 0, boosting the signal) down to 0.8 (last curve, attenuating it).
 * - Which curve each group uses is set by GROUP_VELOCITY_CURVE below.
 * - This ensures a consistent "feel" across the keyboard.
 */
#define VELOCITY_MAP_STRETCH 0.4

// Number of graded velocity curves (the multiplier range above is split into this many steps).
#define VEL_GRADE_STEPS 17

/**
 * GROUP_VELOCITY_CURVE:
 * Velocity curve used by each logical group (A0, D1, G1, ... C8), hand-voiced
 * on the instrument in V1.2. The lowest groups deliberately share curves 4-6
 * (multiplier 1.1-1.05) instead of 0-3, which made the bass too loud.
 * The 18th entry is only used by the C8 group of an 88-key piano.
 */
const byte GROUP_VELOCITY_CURVE[18] = {4, 4, 5, 6, 6, 6, 6, 7, 8, 9, 10, 11, 12, 13, 14, 15, 16, 16};

// PEDAL CALIBRATION (Analog 0-255 range)
#define HIGH_PEDAL_LIMIT 192 // Pedal fully UP
#define LOW_PEDAL_LIMIT 85   // Pedal fully DOWN

// =============================================================

// --- HARDWARE ABSTRACTION ---
const int ALL_CABLE_LINES[18] = {35, 36, 37, 38, 39, 14, 15, 16, 17, 8, 7, 6, 5, 4, 3, 2, 1, 0};

#if PIANO_SIZE == 85
  #define LOGICAL_GROUPS_NEEDED 17
#else
  #define LOGICAL_GROUPS_NEEDED 18
#endif

// Configuration Safety Check
#if (PIANO_SIZE == 88) && (FAULTY_LINE > 0)
  #error "CONFIGURATION ERROR: You cannot use FAULTY_LINE with an 88-key piano. All 18 lines are required."
#endif

// --- STATE MANAGEMENT ARRAYS ---
elapsedMicros hammerTimer[128];        // Measures flight time (Escapement -> Strike)
bool isMeasuringVelocity[128];         // State: Hammer is in the "Flight Zone"
bool strikeDetected[128];              // State: Hammer has hit rail (Debounce latch)
bool noteIsActive[128];                // State: Note is currently sounding

// Lookup Tables
byte velocityMap[VEL_GRADE_STEPS][VEL_MAP_LENGTH];
byte pedalCcTable[256];
int groupLineMap[LOGICAL_GROUPS_NEEDED]; // Logic Group -> Physical Pin Map

// Pedal Throttling
elapsedMillis pedalUpdateTimer;
byte lastPedalMidiValue = 0;
byte lastPedalVoltage = 0;

ADC *adc = new ADC();
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
void loop() {
  // --- MAIN SCANNING LOOP (pipelined) ---
  // Each group's 15 inputs are captured at once, right after its settling time.
  // The captured inputs are processed while the NEXT group is settling, so the
  // settling time is spent on useful work instead of waiting.
  InputSnapshot inputs;

  for (int g = 0; g < LOGICAL_GROUPS_NEEDED; g++) {
    int linePin = groupLineMap[g];

    // 1. Activate Group (Transceivers enabled, Active LOW)
    digitalWriteFast(linePin, LOW);
    uint32_t enabledAt = ARM_DWT_CYCCNT;

    // 2. While this group settles, process the previous group's inputs
    if (g > 0) processGroup(g - 1, inputs);
    waitCyclesSince(enabledAt, MATRIX_SETTLING_CYCLES); // minimum settling time

    // 3. Capture this group's 15 inputs
    readGroupInputs(inputs);

    // 4. Deactivate Group (Transceivers disabled, High Impedance / HIGH)
    digitalWriteFast(linePin, HIGH);

    // 5. Dead Time (the next group must not drive the lines before this one lets go)
    waitCyclesSince(ARM_DWT_CYCCNT, MATRIX_DEAD_TIME_CYCLES);
  }
  processGroup(LOGICAL_GROUPS_NEEDED - 1, inputs);

  // --- THROTTLED PEDAL LOGIC ---
  if (pedalUpdateTimer >= PEDAL_SCAN_INTERVAL_MS) {
    processPedal();
    pedalUpdateTimer = 0;
  }

  usbMIDI.send_now();
}

/**
 * Busy-waits until at least `cycles` CPU cycles have passed since `start`.
 * Unsigned subtraction keeps this correct when the cycle counter wraps around.
 */
static inline void waitCyclesSince(uint32_t start, uint32_t cycles) {
  while ((uint32_t)(ARM_DWT_CYCCNT - start) < cycles) {}
}

/**
 * Captures the 15 check point inputs of the active group (only the port registers
 * that hold check point pins are read).
 */
static inline void readGroupInputs(InputSnapshot &s) {
  int i = 0;
  #define READ_PORT(r) s.port[i++] = isCheckPointPort(&(r)) ? (uint32_t)(r) : 0u;
  INPUT_PORTS(READ_PORT)
  #undef READ_PORT
}

/**
 * Runs the hammer logic for the 5 keys of group g on its captured inputs.
 */
static inline void processGroup(int g, const InputSnapshot &s) {
  byte firstNote = 21 + 5 * g; // Piano starts at A0
  byte curve = GROUP_VELOCITY_CURVE[g];
  checkHammerState(firstNote,     curve, AT_POINT(s, N1_STRIKE), AT_POINT(s, N1_ESCAP), AT_POINT(s, N1_DAMPER));
  checkHammerState(firstNote + 1, curve, AT_POINT(s, N2_STRIKE), AT_POINT(s, N2_ESCAP), AT_POINT(s, N2_DAMPER));
  checkHammerState(firstNote + 2, curve, AT_POINT(s, N3_STRIKE), AT_POINT(s, N3_ESCAP), AT_POINT(s, N3_DAMPER));
  // The last group of an 88-key piano only has 3 keys (A#7-C8).
  if (PIANO_SIZE == 88 && g == 17) return;
  checkHammerState(firstNote + 3, curve, AT_POINT(s, N4_STRIKE), AT_POINT(s, N4_ESCAP), AT_POINT(s, N4_DAMPER));
  checkHammerState(firstNote + 4, curve, AT_POINT(s, N5_STRIKE), AT_POINT(s, N5_ESCAP), AT_POINT(s, N5_DAMPER));
}

/**
 * LOGIC: Determines Hammer State based on Proximity Thresholds.
 * We check from CLOSEST (Strike) to FURTHEST (Damper).
 */
static inline void checkHammerState(byte note, byte curve, bool atStrike, bool atEscap, bool atDamper) {

  // 1. STRIKE ZONE (Closest Proximity)
  // Logic: The hammer is at the peak of travel, closest to the rail.
  if (atStrike) {
    if (!strikeDetected[note]) {
      // Calculate final velocity based on flight time
      unsigned long t = hammerTimer[note];
      byte vel = (t < VEL_MAP_LENGTH) ? velocityMap[curve][t] : 1;

      usbMIDI.sendNoteOn(note, vel, 1);

      strikeDetected[note] = true;
      noteIsActive[note] = true;
    }
  }

  // 2. ESCAPEMENT ZONE (Medium Proximity)
  // Logic: Hammer is close enough to trigger Escapement check point,
  // but NOT close enough to trigger Strike. It is "in flight".
  else if (atEscap) {
    if (!isMeasuringVelocity[note]) {
      // Hammer just entered the Flight Zone from below. Start Timer.
      hammerTimer[note] = 0;
      isMeasuringVelocity[note] = true;
      strikeDetected[note] = false; // Reset latch
    }
  }

  // 3. DAMPER ZONE (Far Proximity)
  // Logic: Hammer is detected by the furthest check point (Damper),
  // but hasn't reached Escapement. It is likely rising slowly or hovering.
  else if (atDamper) {
    // If we drop back down to here from above, abort velocity measurement.
    isMeasuringVelocity[note] = false;
  }

  // 4. OUT OF RANGE (Rest)
  // Logic: Hammer is too far for any check point to get activated (All HIGH).
  else {
    if (noteIsActive[note]) {
      // Hammer has fallen all the way back to rest.
      usbMIDI.sendNoteOn(note, 0, 1); // Note Off
      noteIsActive[note] = false;
    }
  }
}

void processPedal() {
  // Check if ADC has new data ready (prevents stale reads)
  if (adc->adc0->isComplete()) {
    byte voltage = (byte)adc->adc0->analogReadContinuous();

    // Noise Gate: Ignore jitter (optimized without abs() function call)
    int diff = voltage - lastPedalVoltage;
    if (diff > 1 || diff < -1) {
        lastPedalVoltage = voltage;
        byte midiVal = pedalCcTable[voltage];

        if (midiVal != lastPedalMidiValue) {
          lastPedalMidiValue = midiVal;
          usbMIDI.sendControlChange(64, midiVal, 1);
        }
    }
  }
}

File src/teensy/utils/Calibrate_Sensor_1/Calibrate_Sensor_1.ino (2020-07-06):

/**
 * CyberGene's DIY Hybrid Piano Controller
 * For Teensy 3.6 @ 256 MHz
 *
 * This is a calibration program for setting the proper voltage for
 * sensor 1 (the closest to the rail where velocity measurement ends)
 * It is based on an old version of the main code and is rather suboptimal
 * but still works for just a calibration
 *
 * Author: Evgeni Kumanov (CyberGene), cybergene@me.com
 * 2019, 2020
 */
#define note1_1 32
#define note1_2 31
#define note1_3 30
#define note2_1 29
#define note2_2 27
#define note2_3 28
#define note3_1 25
#define note3_2 24
#define note3_3 26
#define note4_1 34
#define note4_2 33
#define note4_3 9
#define note5_1 10
#define note5_2 11
#define note5_3 12

#define GROUP01 35
#define GROUP02 36
#define GROUP03 37
#define GROUP04 38
#define GROUP05 39
#define GROUP06 14
#define GROUP07 15
#define GROUP08 16
#define GROUP09 17
#define GROUP10 8
#define GROUP11 7
#define GROUP12 6
#define GROUP13 5
#define GROUP14 4
#define GROUP15 3
#define GROUP16 2
#define GROUP17 1
#define GROUP18 0
#define LED 13

#define NOTE_A0 21
#define NOTE_D1 26
#define NOTE_G1 31
#define NOTE_C2 36
#define NOTE_F2 41
#define NOTE_Bb2 46
#define NOTE_Eb3 51
#define NOTE_Ab3 56
#define NOTE_Db4 61
#define NOTE_Gb4 66
#define NOTE_B4 71
#define NOTE_E5 76
#define NOTE_A5 81
#define NOTE_D6 86
#define NOTE_G6 91
#define NOTE_C7 96
#define NOTE_F7 101
#define NOTE_A7 105

boolean activated[127];
int currentActive = 0;

void setup() {
  for (int i = 0; i < 127; i++) {
    activated[i] = false;
  }
  Serial.begin(9600);
  pinMode(note1_1, INPUT_PULLUP);
  pinMode(note1_2, INPUT_PULLUP);
  pinMode(note1_3, INPUT_PULLUP);
  pinMode(note2_1, INPUT_PULLUP);
  pinMode(note2_2, INPUT_PULLUP);
  pinMode(note2_3, INPUT_PULLUP);
  pinMode(note3_1, INPUT_PULLUP);
  pinMode(note3_2, INPUT_PULLUP);
  pinMode(note3_3, INPUT_PULLUP);
  pinMode(note4_1, INPUT_PULLUP);
  pinMode(note4_2, INPUT_PULLUP);
  pinMode(note4_3, INPUT_PULLUP);
  pinMode(note5_1, INPUT_PULLUP);
  pinMode(note5_2, INPUT_PULLUP);
  pinMode(note5_3, INPUT_PULLUP);

  pinMode(GROUP01, OUTPUT);
  pinMode(GROUP02, OUTPUT);
  pinMode(GROUP03, OUTPUT);
  pinMode(GROUP04, OUTPUT);
  pinMode(GROUP05, OUTPUT);
  pinMode(GROUP06, OUTPUT);
  pinMode(GROUP07, OUTPUT);
  pinMode(GROUP08, OUTPUT);
  pinMode(GROUP09, OUTPUT);
  pinMode(GROUP10, OUTPUT);
  pinMode(GROUP11, OUTPUT);
  pinMode(GROUP12, OUTPUT);
  pinMode(GROUP13, OUTPUT);
  pinMode(GROUP14, OUTPUT);
  pinMode(GROUP15, OUTPUT);
  //pinMode(GROUP16, OUTPUT);
  pinMode(GROUP17, OUTPUT);
  pinMode(GROUP18, OUTPUT);
  pinMode(LED, OUTPUT);
}

void loop() {
  digitalWriteFast(GROUP01, LOW);
  checkNotes(NOTE_A0);
  digitalWriteFast(GROUP01, HIGH);

  digitalWriteFast(GROUP02, LOW);
  checkNotes(NOTE_D1);
  digitalWriteFast(GROUP02, HIGH);

  digitalWriteFast(GROUP03, LOW);
  checkNotes(NOTE_G1);
  digitalWriteFast(GROUP03, HIGH);

  digitalWriteFast(GROUP04, LOW);
  checkNotes(NOTE_C2);
  digitalWriteFast(GROUP04, HIGH);

  digitalWriteFast(GROUP05, LOW);
  checkNotes(NOTE_F2);
  digitalWriteFast(GROUP05, HIGH);

  digitalWriteFast(GROUP06, LOW);
  checkNotes(NOTE_Bb2);
  digitalWriteFast(GROUP06, HIGH);

  digitalWriteFast(GROUP07, LOW);
  checkNotes(NOTE_Eb3);
  digitalWriteFast(GROUP07, HIGH);

  digitalWriteFast(GROUP08, LOW);
  checkNotes(NOTE_Ab3);
  digitalWriteFast(GROUP08, HIGH);

  digitalWriteFast(GROUP09, LOW);
  checkNotes(NOTE_Db4);
  digitalWriteFast(GROUP09, HIGH);

  digitalWriteFast(GROUP10, LOW);
  checkNotes(NOTE_Gb4);
  digitalWriteFast(GROUP10, HIGH);

  digitalWriteFast(GROUP11, LOW);
  checkNotes(NOTE_B4);
  digitalWriteFast(GROUP11, HIGH);

  digitalWriteFast(GROUP12, LOW);
  checkNotes(NOTE_E5);
  digitalWriteFast(GROUP12, HIGH);

  digitalWriteFast(GROUP13, LOW);
  checkNotes(NOTE_A5);
  digitalWriteFast(GROUP13, HIGH);

  digitalWriteFast(GROUP14, LOW);
  checkNotes(NOTE_D6);
  digitalWriteFast(GROUP14, HIGH);

  digitalWriteFast(GROUP15, LOW);
  checkNotes(NOTE_G6);
  digitalWriteFast(GROUP15, HIGH);

  // DISABLE THIS GROUP DUE TO FAULTY IDC CABLE!!! SHORTED WITH GROUP07
  //digitalWriteFast(GROUP16, LOW);
  //checkNotes(NOTE_C7);
  //digitalWriteFast(GROUP16, HIGH);

  digitalWriteFast(GROUP17, LOW);
  checkNotes(NOTE_C7);
  digitalWriteFast(GROUP17, HIGH);

  digitalWriteFast(GROUP18, LOW);
  checkNotes(NOTE_F7);
  digitalWriteFast(GROUP18, HIGH);
}

void checkNotes(int midiNote) {
  delayMicroseconds(2);

  checkNote(midiNote, digitalReadFast(note1_1) == LOW);
  checkNote(midiNote + 1, digitalReadFast(note2_1) == LOW);
  checkNote(midiNote + 2, digitalReadFast(note3_1) == LOW);
  checkNote(midiNote + 3, digitalReadFast(note4_1) == LOW);
  checkNote(midiNote + 4, digitalReadFast(note5_1) == LOW);
}

void checkNote(int midiNote, boolean active) {
  if (active) {
    if (currentActive == 0) {
      digitalWrite(LED, HIGH);
      currentActive = midiNote;
    }
    if (!activated[midiNote]) {
      activated[midiNote] = true;
      Serial.println(midiNote);
    }
  } else {
    if (midiNote == currentActive) {
      digitalWrite(LED, LOW);
      currentActive = 0;
    }
    if (activated[midiNote]) {
      activated[midiNote] = false;
      Serial.print("*");
      Serial.println(midiNote);
    }
  }
}

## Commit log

2020-04-29 Introduction and the basic principle of the voltage comparator and the optical sensor.
2020-04-29 Rewording and velocity measurement
2020-07-06 The main teensy program code. It contains some customizations, for instance a fix for my faulty IDC cable, calibrations for my Kawai half-pedal, hammer action group weight coefficients, etc. but let 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
    [My_Hybrid_Piano_V1.2.ino]
2020-07-06 The calibration programs for the three sensors. Based on old and ugly code but work for what they are meant to do.
2020-07-06 PCB designs (created in KiCad)
    [My Piano Controller - Sensor (3-wire).sch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]
2020-07-28 Adapt for Teensy 4.1 (A21 analog input pin is now A16), add more quasi-NOOPs
2025-04-29 The complete set of files, since I had forgotten some files on my initial commit
    [My Piano Controller Note Module 3 (5-note, 5V pots).dsn, My Piano Controller Note Module 3 (5-note, 5V pots).kicad_pcb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]
2026-01-04 Switch inputs to INPUT_PULLUP, refine comments
2026-07-10 Add V2 review and redesign plan
    A review of the V1 design (strengths, pain points across hardware,
    firmware, and repo hygiene) and a rough phased plan for a V2 built on
    continuous optical sensing with software thresholds and auto-calibration.
    Claude-Session: https://claude.ai/code/session_012udSGAcZvoYDpRVQYPui6j
2026-09-26 Fix V1.3 regressions against the tested V1.2 firmware
    - Never drive the FAULTY_LINE group pin: it is shorted to another line in the
    cable, so driving it HIGH fought the other group's LOW enable (V1.2 left it
    unconfigured).
    - Restore V1.2's hand-voiced group -> velocity curve mapping
    (GROUP_VELOCITY_CURVE); V1.3 used curve g for group g, making the bass up
    to 11 velocity steps louder.
    - Remove the "< 200us = 127" clamp, which created a jump of up to 11 steps
    in the top treble curves; only t = 0 is special-cased now.
    Velocity tables verified identical to V1.2 on the host. Not yet tested on
    the instrument.
    [My_Hybrid_Piano_V1.3.ino]
2026-09-26 Revise V2 plan after netlist-level hardware and firmware review
    Correct the power budget (~7 W, not 2 W) and add newly found V1 hardware
    issues (LM339 common-mode limit, no hysteresis, no bulk capacitance, power
    sequencing, connector order). Reframe V2's main risk as SNR at the sensor
    rather than sample rate. Replace RP2040 (4 ADC inputs) with STM32G0, drop the
    unneeded clock sync, make the bus 6 wires for auto-addressing, and add a
    latency budget, a "V1.5" alternative and a reference-based Phase 1 exit
    criterion. Add revision notes.
2026-09-26 Add PlatformIO build and give each sketch its own folder
    Arduino tools require a sketch to live in a folder of the same name; main/
    held two sketches, so neither opened directly. Each .ino now has its own
    folder (file names unchanged).
    platformio.ini builds every sketch as its own environment (v1_3, v1_2,
    v1_3_teensy36, calibrate_1..3); scripts/select_sketch.py points each
    environment at its sketch folder. All environments build cleanly.
2026-09-26 Add host simulation tests and GitHub Actions workflow
    test/host simulates the V1 hardware as traced from the netlists (group
    lines, shorted cable line, shared comparator bus, pin map) and plays scripted
    hammer motions through the firmware. run.sh checks that V1.3 produces MIDI
    output identical to the instrument-tested V1.2, that no outputs or note
    boards fight, and that the 88-key configuration behaves the same. The
    original unfixed V1.3 fails these tests.
    The workflow runs the host tests and builds all PlatformIO environments on
    every push and pull request, uploading the .hex files as artifacts.
    [sim.cpp, sim_arduino.h]
2026-09-26 Test against piano behaviour and a reviewed reference, not V1.2
    V1.2 was the first firmware, not a specification. The host tests now check
    the hardware (no line or bus fights) and how a grand action behaves: one
    note per stroke, faster hammer never softer, repetition with the key held,
    aborted presses timed from the second approach, rail rebounds as one note,
    creeping presses at velocity 1. V1.3's output is compared with a reviewed
    reference (test/host/expected/v1_3.txt), updated deliberately with
    UPDATE_EXPECTED=1; the V1.2 comparison is informational.
    V1.3: send pedal updates every 5 ms instead of 20 ms (10 ms average pedal
    latency is noticeable in legato pedalling); the noise gate still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
    [My_Hybrid_Piano_V1.3.ino, sim.cpp]
2026-09-26 V1.3: force-inline the scan, add a group dead time, fix delay comments
    - scanGroup()/checkHammerState() are now always inlined, so pin numbers
    reach digitalReadFast() as constants. GCC had not inlined them, sending
    every read through the pin lookup table: 5260 -> 2677 instructions per
    scan, estimated 11.8 -> 7.8 us typical on Teensy 4.1 (from emulating the
    compiled loop and published GPIO timings).
    - New MATRIX_DEAD_TIME_NS (20 ns) between disabling one group and enabling
    the next, so two transceivers never drive the bus together.
    - The settling-delay comment described it as dead time; it is the wait
    after enabling a group, before reading it.
    Host tests: output identical to the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
    [My_Hybrid_Piano_V1.3.ino]
2026-09-26 V1.3: pipelined scan with port snapshots and compile-time waits
    - Each group's inputs are captured with one read per GPIO port register
    (4 instead of 15 pin reads), and processed while the next group settles,
    so the settling time is spent on useful work. A cycle-counter check still
    guarantees >= MATRIX_SETTLING_DELAY_NS (100 ns) per group.
    - Settling and dead-time waits are compile-time cycle counts on the CPU
    cycle counter instead of delayNanoseconds() (runtime division).
    - Ports come from the Teensy core's CORE_PINn_PINREG/BITMASK; the build
    fails with a named undefined reference if a check point pin is not on a
    snapshotted port, so a wrong mapping cannot silently mute keys.
    E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
    [My_Hybrid_Piano_V1.3.ino, sim.cpp, sim_arduino.h]
2026-09-26 V2 plan: add scan-timing analysis, V1.3 rework and test tooling
    Second revision of the plan: emulator-based scan-time estimates for V1.2
    and V1.3 on Teensy 4.1/3.6 (the recorded 8.9 us fits only a Teensy 4.1),
    the V1.3 rework (inlining, pipelined port snapshots, compile-time waits,
    dead time), V1.2's detection logic checked against grand-action mechanics,
    cable settling and dead-time findings, Phase 0 progress (PlatformIO, CI,
    host tests), and how V2 firmware inherits the test approach.
